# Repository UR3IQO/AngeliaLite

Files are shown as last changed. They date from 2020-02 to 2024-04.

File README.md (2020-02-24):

# **AngeliaLite**
## **Overview**

A two ADCs HF/50MHz direct sampling SDR transceiver with OpenHPSDR v2 compatible protocol.

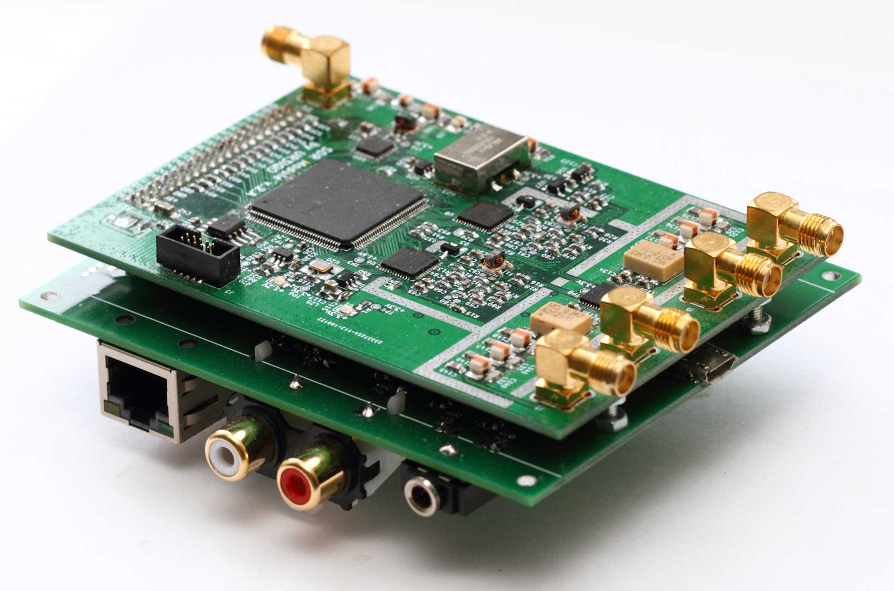
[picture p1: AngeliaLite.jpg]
AngeliaLite SDR transceiver


Some time ago I designed an SDR module for my other projects. The module has two RX inputs (with DVGA and 14bits AD9255 ADC) and one TX output (with 14bits AD9744 DAC). There are also Cyclone 4 FPGA EP4CE22E22, configuration memory and all necessary components for clocking and power it up. The ADCs are clocked at 77.76MHz and the DAC is clocked at 155.52MHz by the low noise ABLJO-155.52MHz VCXO.

The goal of this project was to build a base for the OpenHPSDR compatible SDR transceiver based on that SDR module. The FPGA firmware is based on the OpenHPSDR Angelia code, the NCO code is from the HermesLite2 project. There were many changes in the code to fit 4 DDCs into the relatively small and low pin count EP4CE22E22 FPGA, some changes were requied because of the different ADC/DAC sample rates.

The second board contains Eternet PHY, standard ALEX, OC, keyer and PTT interfaces, four analog inputs, diagnostic LEDs, switching regulator (so it can be powered from the single 12V supply). There is also STM32F072 MCU on the secons board.

You need to add some RX filtering and TX amplifier with LPFs to get a full featured transceiver.

**There are some limitations:**
* The maximun supported output samplerate is 192kSPS
* There is no audio CODEC on the boards
* The Ethernet connection has 100Mbit/s speed
* The ADC opaerates on the second Nyquist zone on 50MHz band. The board has LPF filter with 65MHz cutoff frequency, so additional selectivity is needed to avoid images reception. It can be as simple as switchable 30MHz LPF and 50MHz bandpass filter.
* There is no TX power amplifier at the DAC output - just an LPF filter-diplexer. So, you will need some amplfication/filtering in the TX path.
* Altera USBBlaster or similar JTAG adapter is needed for FPGA firmware update

The SDR operates with the ***SDR Console v3*** and ***Thetis***.

## **Specifications**
**General**| |
:-|-|
Architecture | *Direct Sampling DDC/DUC Transceiver*  |
Interface | *Ethernet (100Mb/s)*  
TCXO Stability | *±0.5 PPM*  
RX ports | *Two SMA connectors (each ADC has dedicated input)*  
TX ports | *SMA connector* 

**Electrical**|
:-|
13.8v DC @ 0.5A|

**Mechanical** | |
:-|-|
Weight | *100g (approx.)*  
Dimensions (two boards stacked) | *100mm x 85mm x 35mm*

**Receiver**| |
:-|-|
Receiver Architecture | *Direct Sampling / Digital Down Conversion*  
ADC | *Dual 14 bit Phase Synchronous ADCs @ 77.76MSPS. Hardware supports 4 independent receivers assignable to either ADC*  
Frequency Coverage | *1MHz to 35MHz (1st Nyquist zone) and 45MHz to 65MHz (2nd Nyquist zone), reception below 1MHz is possible with some RX parameters degradation*  
Input filtering | *LPF with 65MHz cutoff frequency*  
Attenuator | *0..31dB 1dB step attenuator*  

**Transmitter**| |
:-|-|
Transmitter Architecture | *Digital Up Conversion*  
DAC | *14 bit @ 155.52MSPS*  
RF Output Power | *-3dBm*
Transmitter phase noise | -140dBc/Hz (at >1kHz offset and max. drive settings)

**IOs:**|
:-|
RCA PTT in, PTT Out |
3.5mm Jack CW Key |
2.54mm pin headers for ALEX, 7 freely programmable open collector outputs, analog Inputs (4channel + power supply monitoring), two digital inputs |
SMA connector for 10MHz reference input/output |
SMA connector for 155.52MHz reference output |
RJ45 Ethernet LAN Connector |

## **Measurements**
The receiver BW was 500Hz during the measurements.

### **MDS / NF / FS level / BDR**

ATT | MDS | NF | FS level | BDR |
---: | ---: | ---: | ---: | ---: |
  0dB| -133dBm | 14dB | -13dBm | 120dB |  
-10dB| -127dBm | 20dB | -2dBm | 125dB |
-20dB| -117dBm | 30dB | +9dBm | 126dB |
-30dB| -107dBm | 40dB | - | - |

### **RMDR / SSB noise**

Offset | RMDR | SSB noise
---: | ---: | ---:
1kHz | 111dB | -138dBc/Hz
2kHz | 113dB | -140dBc/Hz
5kHz | 117dB | -144dBc/Hz
10kHz | 121dB | -148dBc/Hz
20kHz | 124dB | -151dBc/Hz

### **IMD3 Performance**

The usual method of determining IMD3 receiver performance does not give useful data when testing direct sampling receiver (because of IMD products does not follow cubical law). So, the IMD3 performance data presented in graphical form showing IM3 levels depending of the test tones levels for the different attenuator settings.

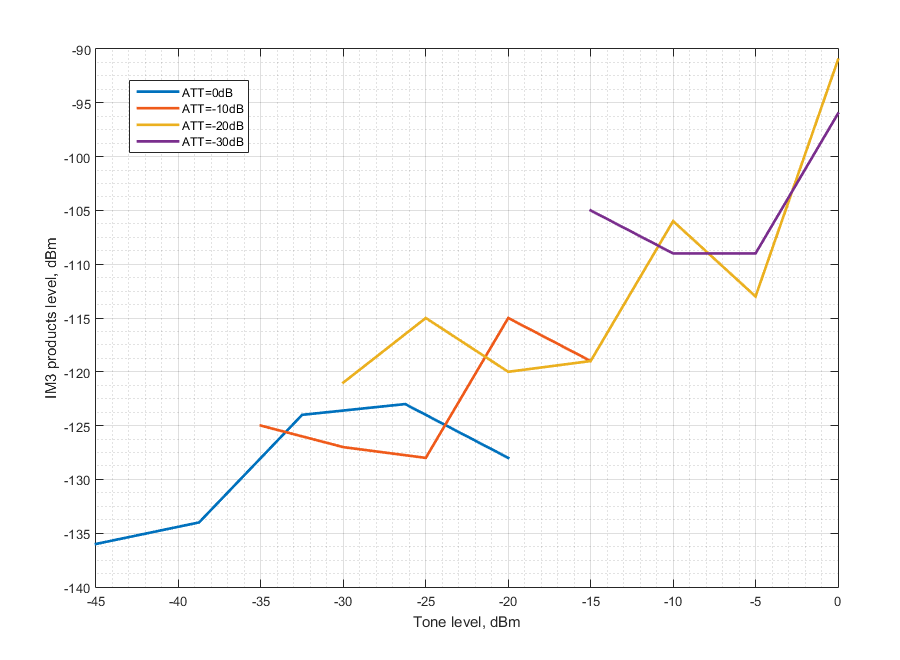
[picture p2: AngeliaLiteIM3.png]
IMD3 Performance


## **Image rejection and DDC Decimation Filters**

AngeliaLite uses different ADC/DAC sampling frequencies, so all decimation stages and filters were redesigned for the new decimation ratios.  

### **SDR module input (analog LPF)**

LPF filter at the SDR module input rejects ADC aliases. Only signals in the 1st and 2nd Nyquist zones passed. As you can see some additional filtering is required to separate signals in the first and second zones and improove rejection in the third and higher zones. Here is the LPF response:

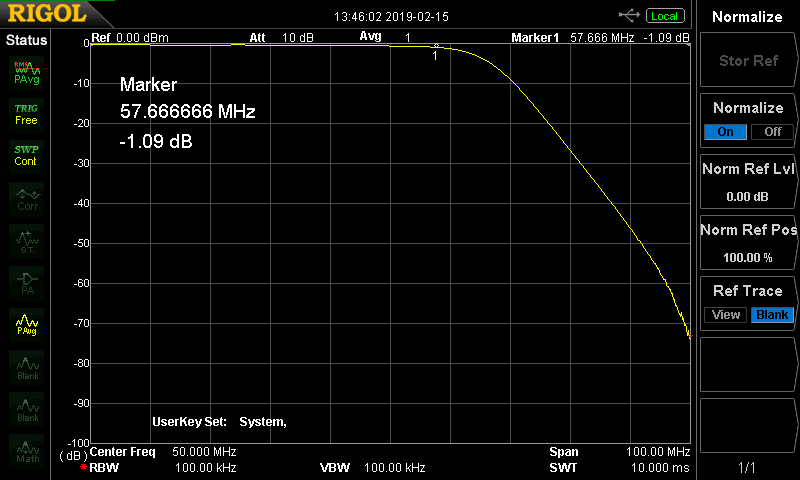
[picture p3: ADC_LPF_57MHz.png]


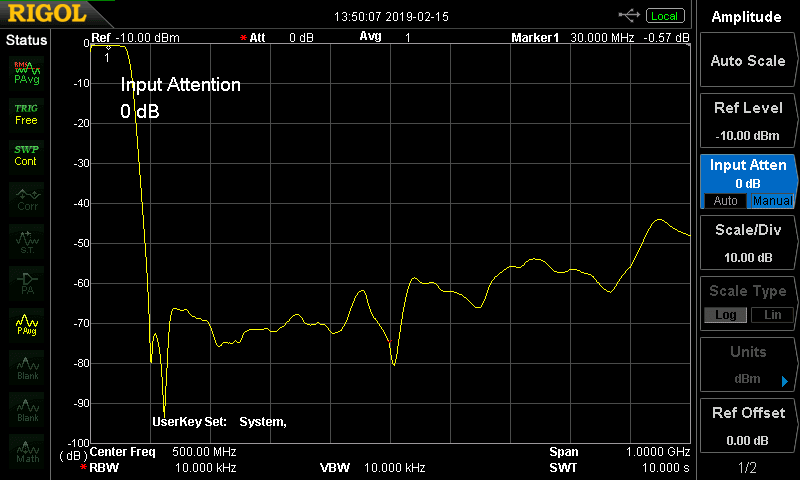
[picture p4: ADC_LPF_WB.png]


### **First stage 9x decimation (digital CIC filter)**

When the signal is decimated aliasing occurs, so some filtering is needed. CIC filter provides such filtering for the first 9x decimation. The worst case alias rejection is **116dB**. Here is the filter response:

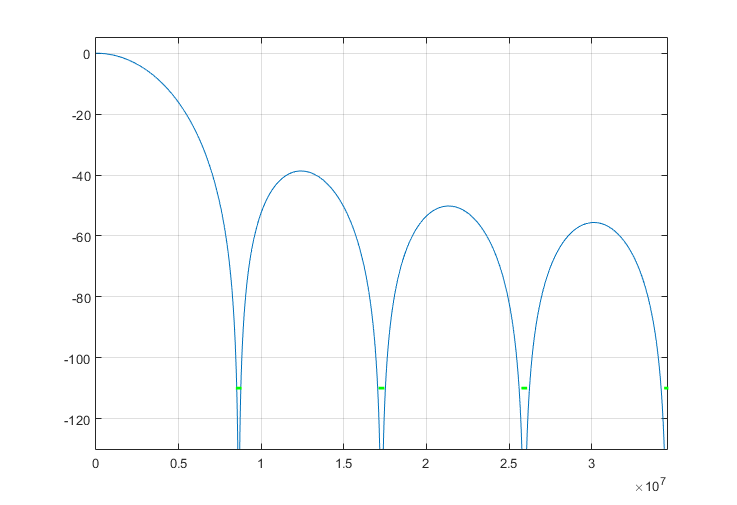
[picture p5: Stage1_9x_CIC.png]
First stage CIC


### **Second stage 5x/10x/20x decimation (digital CIC flter)**

The second decimation stage and one more CIC filter. The worst case alial rejection is **121dB** (for 5x decimation 96kHz bandwidth). Here is filter response:

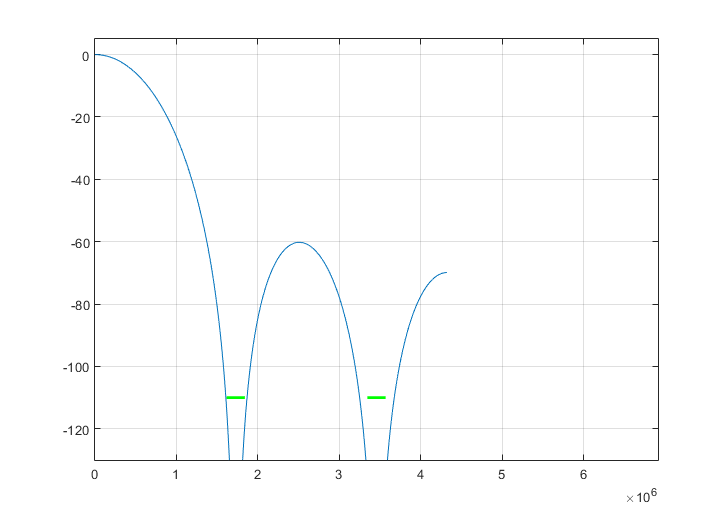
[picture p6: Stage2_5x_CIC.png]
Second stage CIC


### **Third stage 9x decimation (digital FIR filter)**

The aliases of the last decimation by 9 are suppressed by the FIR filter. AngeliaLite uses relatively small and inexpensive FPGA, so last stage FIR filter is optimized for the minimum logic/memory FPGA resources use. The performance is limited by the 18bits FIR filter coefficients, but rejection is still at a respectable **100dB**. Here are the calculated ideal filter response (blue line) and the real one with quantized coefficients (red line):

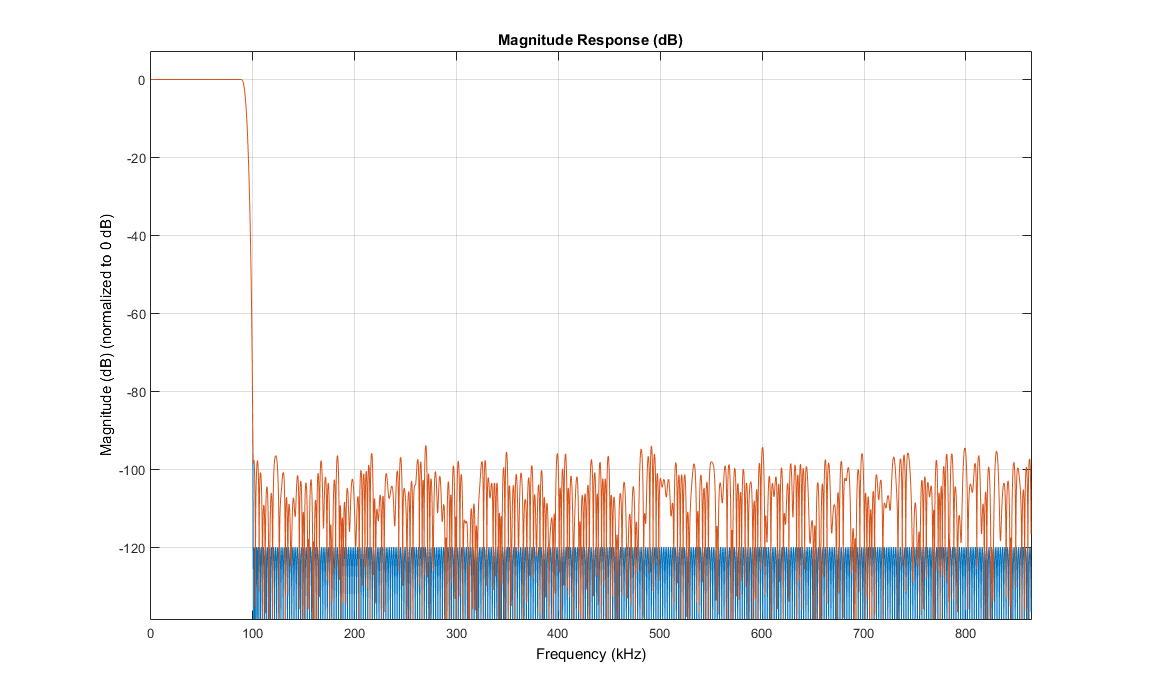
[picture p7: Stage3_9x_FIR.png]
Third stage FIR


## **Board connections**
**SDR module**
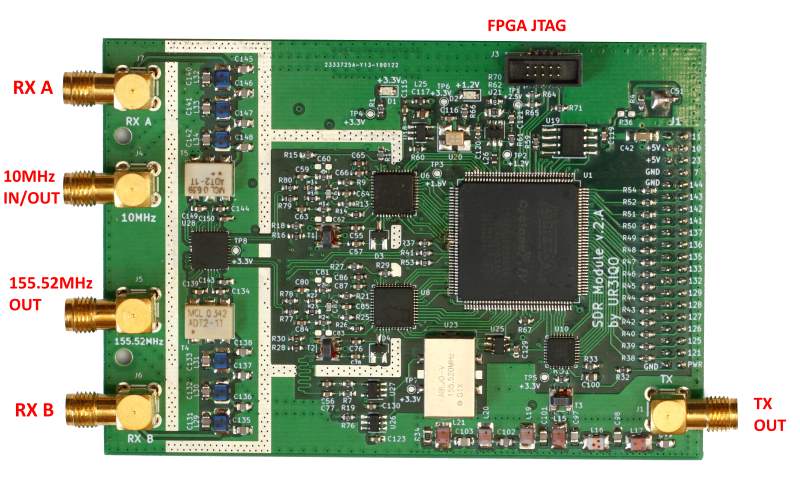
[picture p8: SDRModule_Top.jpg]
SDR module by UR3IQO


**AngeliaLite mainboard**
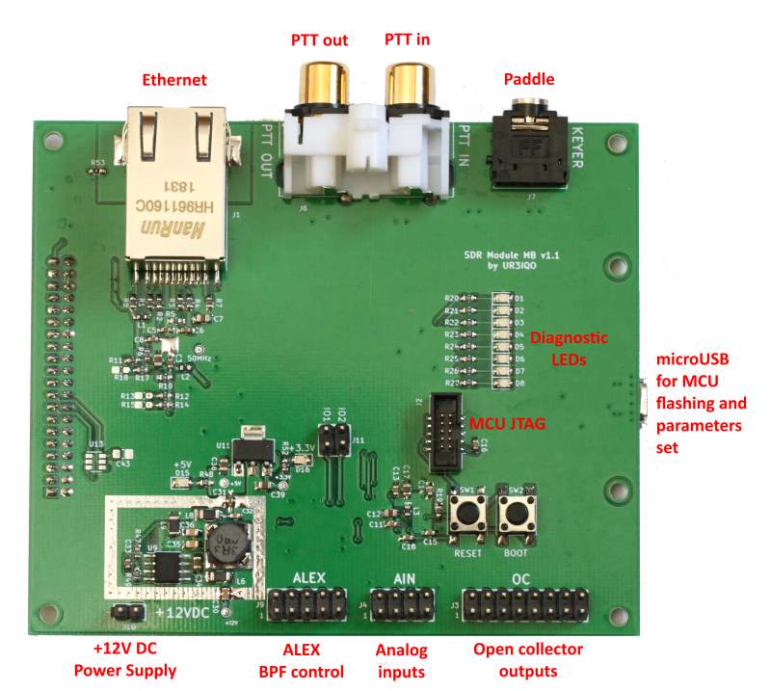
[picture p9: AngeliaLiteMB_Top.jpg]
AngeliaLite Motherboard


73!
Oleg UR3IQO

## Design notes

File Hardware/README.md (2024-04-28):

# SDRModule and AngeliaLite Mainboard
In this folder you can find SDR module and AngeliaLite Mainboard schematics.

# Assembly instructions
## AngeliaLite Mainboard v1.1
***Important!***

Do ***not install*** the following components:
- U10 (74LVC1G04)
- U13 (25AA02E48T)
- C37
- C43
- R13
- R15
- R18
- R50
- R59
- R32
- R35

***Install*** the following components: 
- R17 10 kOhm
- R33 0 Ohm
- R34 0 Ohm

## SDRModule v2.B
Do ***not install*** the following components:
- R35
- R72
- R75
- L23

Assemble the power supply circuits firstly and do a brief check. Proceed with the other components when you see the correct voltages supplyed by the regulators. This may save you some money and time ;)

# Troubleshooting

## Diagnostic LEDs on the Motherboard 
- **LED1** flash for ~0.2 second whenever the PHY receives (rgmii_rx_activ)
- **LED2** flash for ~0.2 second whenever the PHY transmits (rgmii_tx_active)
- **LED3** is not used
- **LED4** flash for ~0.2 seconds whenever traffic to the boards MAC address is received 
- **LED5** displays state of Ethernet PHY negotiations:
   - fast flash if no Ethernet connection
   - slow flash if 100T
   - swaps between fast and slow flash if not full duplex
- **LED6** displays state of DHCP negotiations:
   - on if success
   - slow flash if fail
   - fast flash if time out 
   - swap between fast and slow if using a static IP address
- **LED7** flash for ~0.2 seconds whenever udp_rx_active
- **LED8** (**STATUS**) flash if FPGA and MCU firmware are running and FPGA<->MCU SPI bus operates properly

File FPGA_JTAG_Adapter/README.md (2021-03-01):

# **AngeliaLite**
## **FPGA JTAG Adapter**

This directory contains schematics and gerber files for the JTAG adapter. It is used to connect the standard 2x5 pins 2.54mm pin grid connector (used in the Altera Byte Blaster or other similar JTAG cables) to the miniature BH1.27-10SMD connector used in the AngeliaLite.

The pinouts of the both connectors are the same. The connectors are mounted on the opposite sides of the PCB:

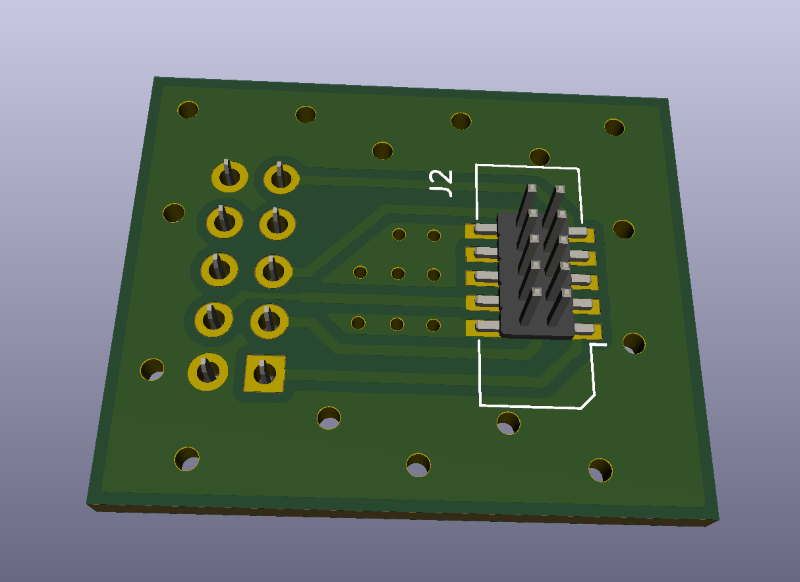
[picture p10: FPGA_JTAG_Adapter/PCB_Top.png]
FPGA JTAG Adapter PCB top

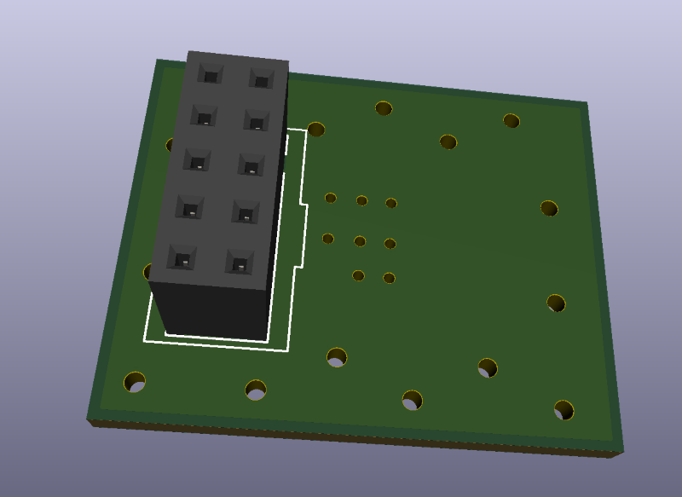
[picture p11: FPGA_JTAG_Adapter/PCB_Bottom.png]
FPGA JTAG Adapter PCB bottom


## **How to use the adapter**

The usage is straightforward - just plug the adapter to the Altera USB Byte Blaster (or compatible JTAG cable). And use the flat cable with two IDC1.27-10 sockets to connect adapter and AngeliaLite board.

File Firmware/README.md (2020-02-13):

# Firmware for the AngeliaLite
The FPGA folder contains FPGA source code and binaries for the SDR module Cyclone 4 FPGA.  
The MCU folder contains binary (DFU image) for the STM32F072 MCU

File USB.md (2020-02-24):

# **How to use microUSB port on the AngeliaLite Mainboard**

There is a microUSB connector on the AngeliaLite Mainboard. It is connected to the board MCU (STM32F072) and is used to:
- Firmware flashing to the MCU
- Checking MAC/IP addresses 
- Seting IP address (and also to select DHCP/static IP)

## **Firmware flashing**
You can flash the MCU firmware using the ST DFU utilities for the STM32. Connect AngeliaLite Mainboard to the PC computer (using microUSB-USB cable), turn it on holding BOOT button, release BOOT button. The MCU will enter bootloader mode and you will be able to flash it.

## **Setting IP address**
By default AngeliaLite uses DHCP to obtain valid IP address or rolls back to APIPA address if it can not get IP address. You can program static IP address useing microUSB port on the AngeliaLite Mainboard.

Connect AngeliaLite Mainboard to the PC computer (using microUSB-USB cable), turn it on. A new communication port should be found by your PC. Connect to those port using terminal software (for example Putty), use default parameters.

After connection the following commands will be available:
| Command | Description |
|---|---|
|**H;** | Brief help message|
|**I;**|show IP address|
|**I aaa.bbb.ccc.ddd;**|set static IP address *aaa.bbb.ccc.ddd*|
|**I DHCP;**|obtain IP address from DHCP server or use APIPA|adress if DHCP fails
|**M;**|show MAC address|
|**V;**|show firmware version and serial number|

The changes will be effective after the board restarts

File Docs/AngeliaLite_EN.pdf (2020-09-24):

## AngeliaLite - OpenHPSDR compatible transceiver

Oleg Skydan UR3IQO

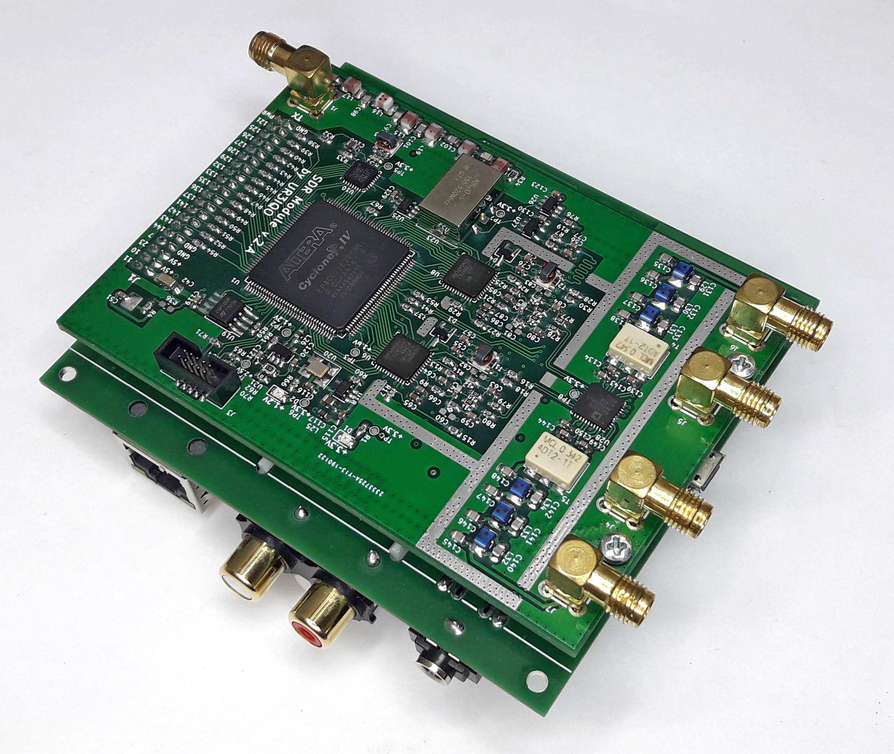
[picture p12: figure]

### Description

AngeliaLite is intended to be used as the base of the OpenHPSDR compatible transceiver. You need to add just some additional filtering for receiver and PA/LPFs for transmitter to make a full featured high performance HF SDR transceiver. A VHF/microwave transceiver can also be made by adding transverter to the AngeliaLite.

AngeliaLite consists of two boards - the SDR module and the interface board.

The SDR module has two RX inputs (with DVGA and 14bits AD9255 ADC) and one TX output (with 14bits AD9744 DAC). There are also Cyclone 4 FPGA EP4CE22E22, configuration memory and all necessary components for clocking and power it up. The ADCs are clocked at 77.76MHz and the DAC is clocked at 155.52MHz by the low noise ABLJO-155.52MHz VCXO.

The interface board contains Eternet PHY, standard ALEX, OC, keyer and PTT interfaces, four analog inputs, diagnostic LEDs, switching regulator (so it can be powered from the single 12V supply), microcontroller (used to interface SDR module to standard OpenHPSDR interfaces, IP and MAC addresses management) and power supply to power boards from the single 12V power supply.

The schematics for both boards, FPGA source code and FPGA/MCU compiled firmware are available on the GitHub (https://github.com/UR3IQO/AngeliaLite ).

The FPGA firmware is based on the OpenHPSDR Angelia code, the NCO code is from the HermesLite2 project. There were many changes in the code to fit 4 DDCs into the relatively small and low pin count EP4CE22E22 FPGA, some changes were required because of the different ADC/DAC sample rates and different Ethernet PHY chip.

There are some limitations compared to the OpenHPSDR Angelia board:

- The maximum supported output samplerate is 192kSPS.
- There is no audio CODEC on the boards.
- The Ethernet connection has 100Mbit/s speed.
- The ADC operates on the second Nyquist zone on 50MHz band. The board has LPF filter with 60MHz cutoff frequency, so additional selectivity is needed to avoid image reception. It can be as simple as switchable 30MHz LPF and 50MHz bandpass filter.
- There is no TX power amplifier at the DAC output - just an LPF filter-diplexer. So, you will need some amplification/filtering in the TX path.
- Altera USBBlaster or similar JTAG adapter is needed for FPGA firmware update

The FPGA code implements OpenHPSDR protocol version 2. The AngeliaLite operates with the SDR Console v3 and Thetis.

### Specifications

General
Architecture | Direct Sampling DDC/DUC Transceiver
Interface | Ethernet (100Mb/s)
TCXO Stability | ±0.5 ppm
RX ports | Two SMA connectors (each ADC has dedicated input)
TX ports | SMA connector

Electrical
Supply voltage | 8..15V DC
Supply current | 0.5A

Mechanical
Weight | 100g (approx.)
Dimensions (two boards stacked) | 100mm x 85mm x 35mm

Receiver
Receiver Architecture | Direct Sampling / Digital Down Conversion
ADC | Two 14 bit Phase Synchronous ADCs @ 77.76MSPS. Hardware supports 4 independent receivers assignable to either ADC
Frequency Coverage | 1MHz to 35MHz (1st Nyquist zone) and 45MHz to 65MHz (2nd Nyquist zone), reception below 1MHz is possible with some RX parameters degradation
Input filtering | LPF with 65MHz cutoff frequency
Attenuator | 0..31dB 1dB step attenuator

Transmitter
Transmitter Architecture | Digital Up Conversion
DAC | 14 bit @ 155.52MSPS
RF Output Power | -3..-5dBm
Transmitter phase noise | -140dBc/Hz (at >1kHz offset and max. drive settings)

IO interfaces
RCA PTT in, PTT Out
3.5mm Jack CW Key
2.54mm pin headers for ALEX, 7 freely programmable open collector outputs, analog Inputs (4channel + power supply monitoring), two digital inputs
SMA connector for 10MHz reference input/output
SMA connector for 155.52MHz reference output
RJ45 Ethernet LAN Connector

### Receiver measurements

The BDR/RMDR/IMD tests were made using two ultra low noise XTAL oscillators. The receiver bandwidth was 500Hz during these tests.

MDS / NF / FS level / BDR
ATT | MDS | NF | FS level | BDR
0dB | -133dBm | 14dB | -13dBm | 120dB
-10dB | -127dBm | 20dB | -2dBm | 125dB
-20dB | -117dBm | 30dB | +9dBm | 126dB
-30dB | -107dBm | 40dB | - | -

RMDR / SSB noise
Offset | RMDR | SSB noise
1kHz | 111dB | -138dBc/Hz
2kHz | 113dB | -140dBc/Hz
5kHz | 117dB | -144dBc/Hz
10kHz | 121dB | -148dBc/Hz
20kHz | 124dB | -151dBc/Hz

IMD3 Performance

The usual method of determining IMD3 receiver performance does not give useful data when testing direct sampling receiver (because of IMD products does not follow cubical law). So, the IMD3 performance data presented in graphical form showing IM3 levels depending of the test tones levels for the different attenuator settings.

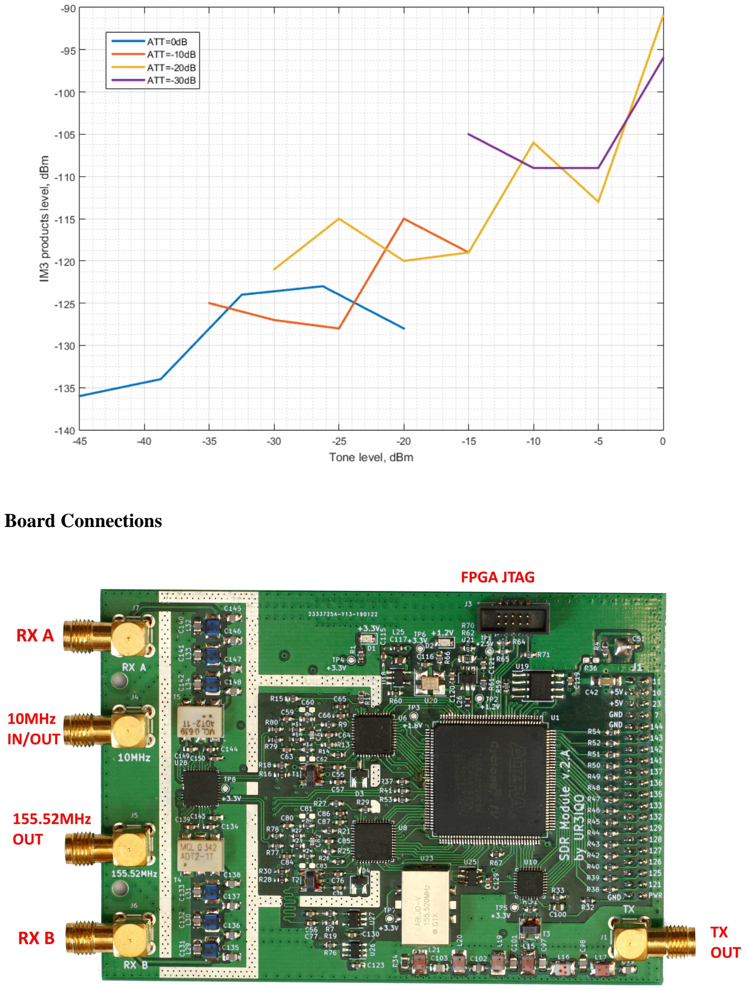
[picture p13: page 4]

Board Connections

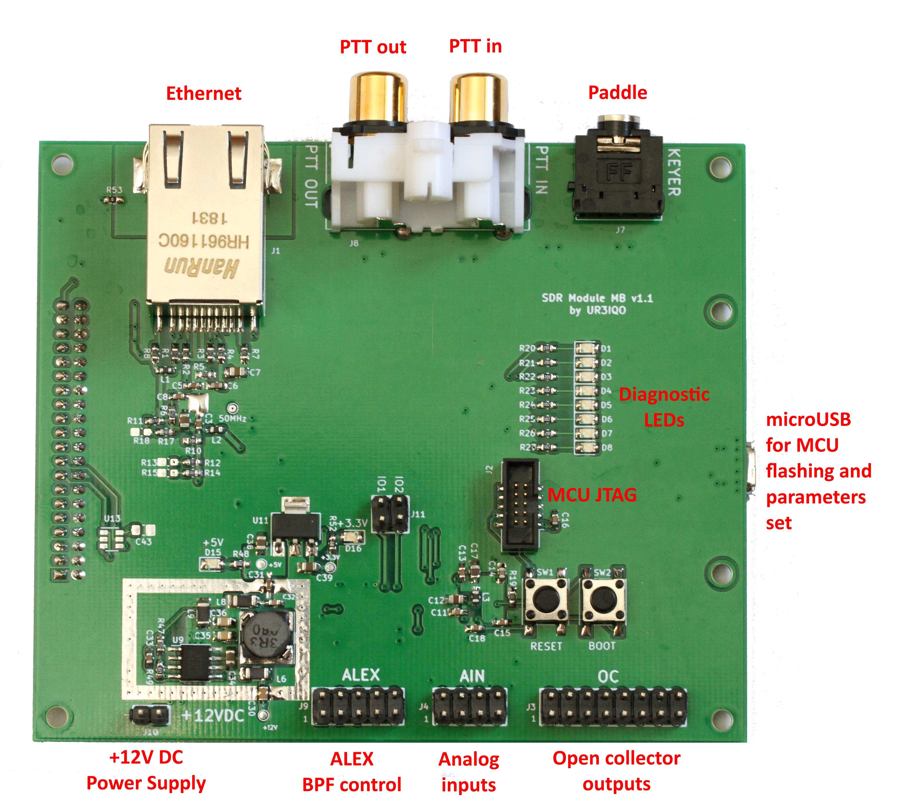
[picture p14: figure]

### Using the USB port on the interface board

Using the USB port on the interface board you can:
- update MCU firmware
- selecting IP address assignment and set static IP address
- check the board MAC address and serial number
- check MCU firmware version
- set ADC dither override options

Connecting to the AngeliaLite service console

Connect microUSB port on the board to the computer and turn on the AngeliLite power supply. The computer will install the virtual COM port driver. Open Device Manager to check the port number assigned to the board. Run terminal program (the PuTTY will be used in examples).

Set the COM port number assigned to the board:

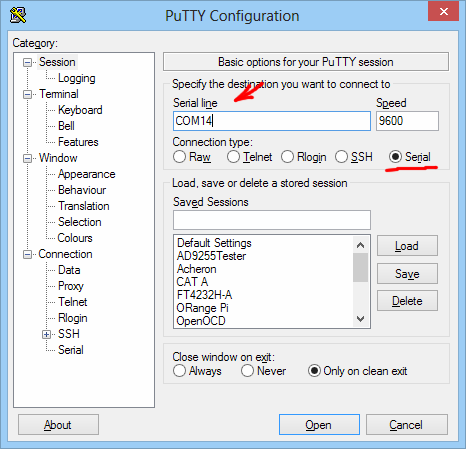
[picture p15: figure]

Set Local Echo terminal option:

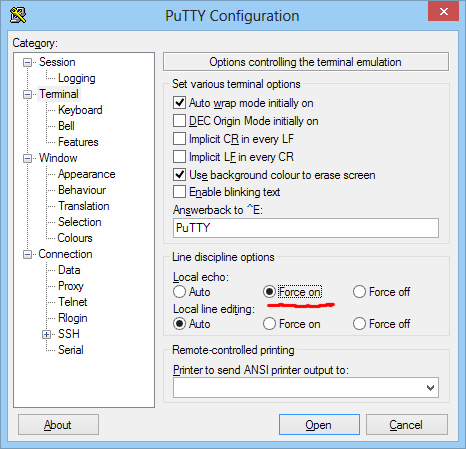
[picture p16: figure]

Now press the Connect button, the terminal window with AngeliaLite service console will open.

The command you can issue in the AngeliaLite service console starts with the command (one letter) following by optional command parameter, each command ends with the semicolon.

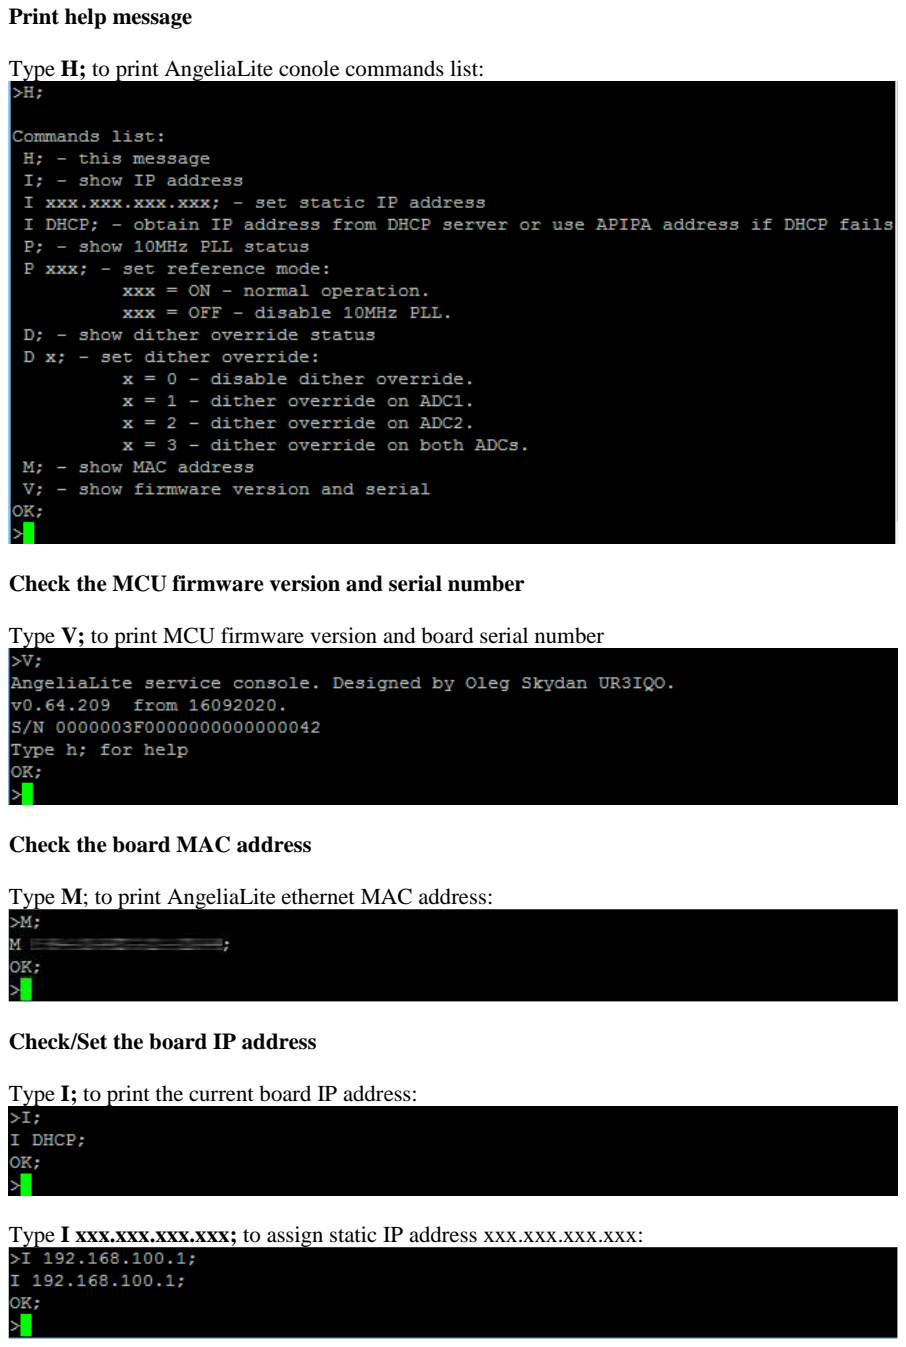
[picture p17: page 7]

Print help message

Type H; to print AngeliaLite conole commands list:

Check the MCU firmware version and serial number

Type V; to print MCU firmware version and board serial number

Check the board MAC address

Type M; to print AngeliaLite ethernet MAC address:

Check/Set the board IP address

Type I; to print the current board IP address:

Type I xxx.xxx.xxx.xxx; to assign static IP address xxx.xxx.xxx.xxx:

Type I DHCP; to use DHCP to assign IP addres or APIPA address if DHCP will fail

NOTE: you should cycle the power of the AngeliaLite to use the new IP address.

Check/Set ADC dithering override

It is recommended to keep ADC dithering enabled for the AngeliaLite, but the SDR software may not allow user to control ADC dithering. So there is ADC dithering override option that can be controlled using the AngeliaLite service console. If the dithering override bit is set the ADC dithering will be turned on independently of the SDR software settings.

Type D; to check the ADC dithering override status:

Type D x; to change ADC dithering override flags:

See the table below for the x parameter description:
Parameter value | Description
0 | ADC dithering override is OFF, the SDR software will control dithering
1 | ADC dithering override is ON for the ADC1 only
2 | ADC dithering override is ON for the ADC2 only
3 | ADC dithering override is ON for both ADCs

Close the terminal program and disconnect USB cable when you done with the AngeliaLite service console.

Updating MCU firmware

You will need DfuSe Demo software available at the ST web site: https://www.st.com/en/development-tools/stsw-stm32080.html

Connect board to the computer USB port, turn the board power on when holding the BOOT button on the interface board. Alternatively you can hold the BOOT button and press the RESET button. Then release the BOOT button. The MCU will start the internal DFU bootloader and you will be able to flash it using the DFU image from the AngeliaLite GitHub: https://github.com/UR3IQO/AngeliaLite/tree/master/Firmware/MCU

Please see DfuSe Demo documentation how to load the image into the MCU flash memory.

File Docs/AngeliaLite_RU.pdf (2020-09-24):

# AngeliaLite - OpenHPSDR совместимый трансивер

Олег Скидан UR3IQO


### Введение

AngeliaLite предназначен | для | использования | в | качестве | основы | OpenHPSDR
совместимого трансивера. Для того чтобы получить полноценный SDR КВ трансивер достаточно добавить фильтры на вход приемника и усилитель мощности с ФНЧ. Также AngeliaLite удобен для работы на УКВ/СВЧ диапазонах - достаточно подключить трансвертер, чтобы получить полноценный SDR УКВ трансивер.

AngeliaLite состоит из двух плат - SDR модуля и интерфейсной платы.

У SDR модуля два входа приемников (каждый с программируемым УВЧ и 14битным АЦП AD9255) и один выход передатчика (используется 14битный ЦАП AD9744). Также на плате SDR модуля установлены ПЛИС Cyclone 4 EP4CE22E22, конфигурационная память, а также все необходимые компоненты для питания и тактирования различных элементов модуля. Тактирование модуля осуществляется от малошумящего кварцевого генератора ABLJO-155.52MHz. Тактовая частота АЦП 77.76MHz, ЦАП работает на
частоте 155.52MHz.

Интерфейсная плата содержит Ethernet PHY, стандартные интерфейсы ALEX, OC, интерфейсы для подключения манипулятора телеграфного ключа и PTT, четыре аналоговых входа, диагностические светодиоды, импульсный стабилизатор +5В (который позволяет трансиверу работать в широком диапазоне питающих напряжений с минимальным нагревом и хорошей эффективностью и микроконтроллер (который используется для управления IP/MAC адресацией и обеспечивает работу стандартных интерфейсов OpenHPSDR).

Принципиальные схемы обеих плат, а также исходный код для ПЛИС и скомпилированные прошивки для ПЛИС и микроконтроллера доступны на GitHub
(https://github.com/UR3IQO/AngeliaLite ).

Прошивка ПЛИС основана на исходном коде проекта OpenHPSDR Angelia, NCO используется от проекта HermesLite2. В исходный код было внесено много изменений для того, чтобы в ПЛИС с небольшой логической емкостью вместить четыре приемника. Также изменения потребовались в силу других частот дискретизации АЦП/ЦАП (все децимационные/интерполяционные фильтры были заново пересчитаны, а децимационный КИХ фильтр приемника был полностью переписан заново), а также использования
другого чипа Ethernet PHY.

AngeliaLite имеет некоторые ограничения по сравнению с оригинальным проектом

### OpenHPSDR Angelia:

- Максимально поддерживаемая частота дискретизации на выходе DDC 192kSPS.
- На плате нет аудиокодека.
- Подключение по Ethernet осуществляется со скоростью 100Mbit/s.
- В диапазоне 50МГц АЦП работает во второй зоне Найквиста. На плате установлены ФНЧ с частотой среза около 60МГц, поэтому требуется дополнительная фильтрация, чтобы подавить наложения. Достаточно простого ФНЧ с частотой среза 30МГц и полосового фильтра на диапазон 50МГц.
- На плате нет драйвера передатчика. Поэтому может потребоваться дополнительное усиление сигнала для подключения усилителя мощности.
- Для обновления прошивки потребуется Altera USBBlaster или аналогичный JTAG адаптер

В прошивке ПЛИС реализован "новый" протокол OpenHPSDR (протокол второй версии).
AngeliaLite может работать с программами SDR Console v3 и Thetis.

### Параметры

Общие
Архитектура | DDC/DUC трансивер с прямой оцифровкой
Интерфейс | Ethernet (100Mb/s)
Стабильность TCXO | ±0.5 ppm
Подключение приемника | Два SMA разъема (отдельный вход для каждого АЦП)
Подключение передатчика | SMA разъем
Вес | Около 100гр
Размеры (сборка из двух плат) | 100mm x 85mm x 35mm

Питание
Напряжение источника питания | 8..15V DC
Потребляемый ток | <0.5A

Приемник
Архитектура приемника | Прямая оцифровка
АЦП | Два 14 битных АЦП работающих с частотой дискретизации 77.76MSPS и синхронизированных по фазе. Поддерживается до 4х независимых приемников подключаемых к любому АЦП
Диапазон частот | 1..35MHz (первая зона Найквиста) 45..65MHz (вторая зона Найквиста) возможен прием ниже 1MHz с некоторым ухудшением параметров
Входная фильтрация | ФНЧ с частотой среза 60МHz
Аттенюатор | 0..31dB с шагом 1dB

Передатчик
Архитектура передатчика | Прямое формирование на частоте передачи
ЦАП | 14 бит @ 155.52MSPS
Выходная мощность | -3..-5dBm
Фазовый шум на выходе передатчика | -140dBc/Hz (при отстройке более 1kHz и установленной максимальной мощности)

Интерфейсы

### RCA PTT вход, PTT выход

3.5mm Jack для подключения CW манипулятора
Штыревые разъемы с шагом 2.54mm (для подключения ПФ ALEX, 7 свободно программируемых выходов, аналоговые входы - 4 канала и мониторинг напряжения питания), два цифровых входа
SMA разъем для входа/выхода опорного сигнала с частотой 10MHz
SMA разъем с опорным сигналом 155.52MHz
RJ45 Ethernet разъем подключения компьютерной сети

### Измерения параметров приемников

Измерения BDR/RMDR/IMD3 DR проводились с использованием ультра малошумящих кварцевых генераторов (уровень бокового шума менее -180дБн/Гц при отстройке более 10кГц). Полоса пропускания приемника при проведении тестов была 500Гц.

### MDS / NF / FS level / BDR

ATT | MDS | NF | Уровень FS | BDR
0dB | -133dBm | 14dB | -13dBm | 120dB
-10dB | -127dBm | 20dB | -2dBm | 125dB
-20dB | -117dBm | 30dB | +9dBm | 126dB
-30dB | -107dBm | 40dB | - | -

### RMDR / шум

Отстройка | RMDR | Шум
1kHz | 111dB | -138dBc/Hz
2kHz | 113dB | -140dBc/Hz
5kHz | 117dB | -144dBc/Hz
10kHz | 121dB | -148dBc/Hz
20kHz | 124dB | -151dBc/Hz

Динамический диапазон по интермодуляции третьего порядка

У приемников с прямой оцифровкой уровень продуктов интермодуляции может не следовать кубическому закону. Поэтому традиционные методы, используемые, чтобы охарактеризовать ДД приемника по интермодуляции третьего порядка, плохо подходят. ДД приемника по интермодуляции третьего порядка приведен в виде графика, показывающего уровень продуктов интермодуляции в зависимости от уровня испытательного двухтонового сигнала (по оси Х приведены уровни одного тона двухтонового тестового сигнала) для разных установок коэффициента усиления DVGA (приведены значения соответствующие установкам аттенюатора в программах Thetis и

### SDR Console):

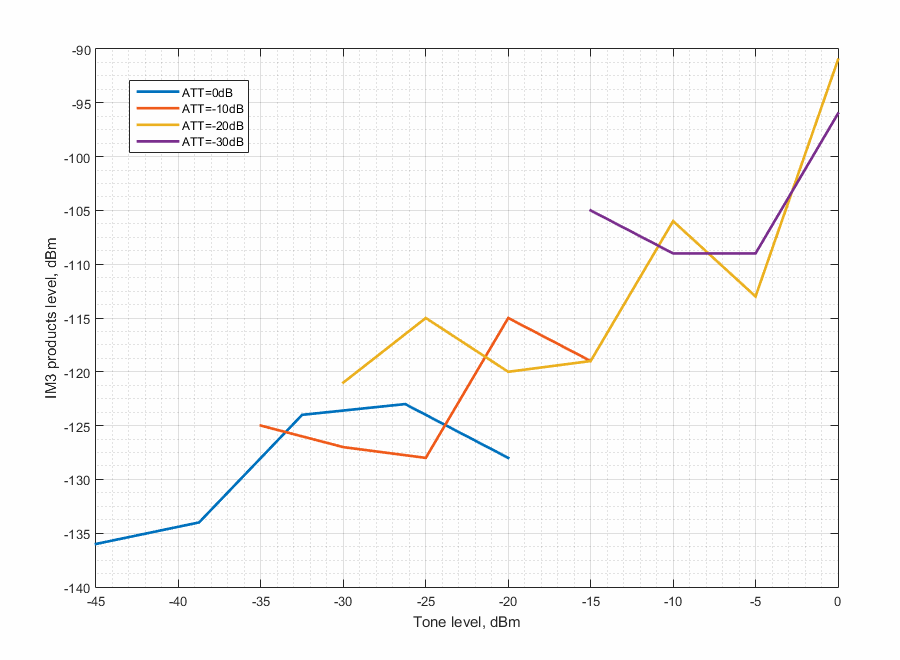
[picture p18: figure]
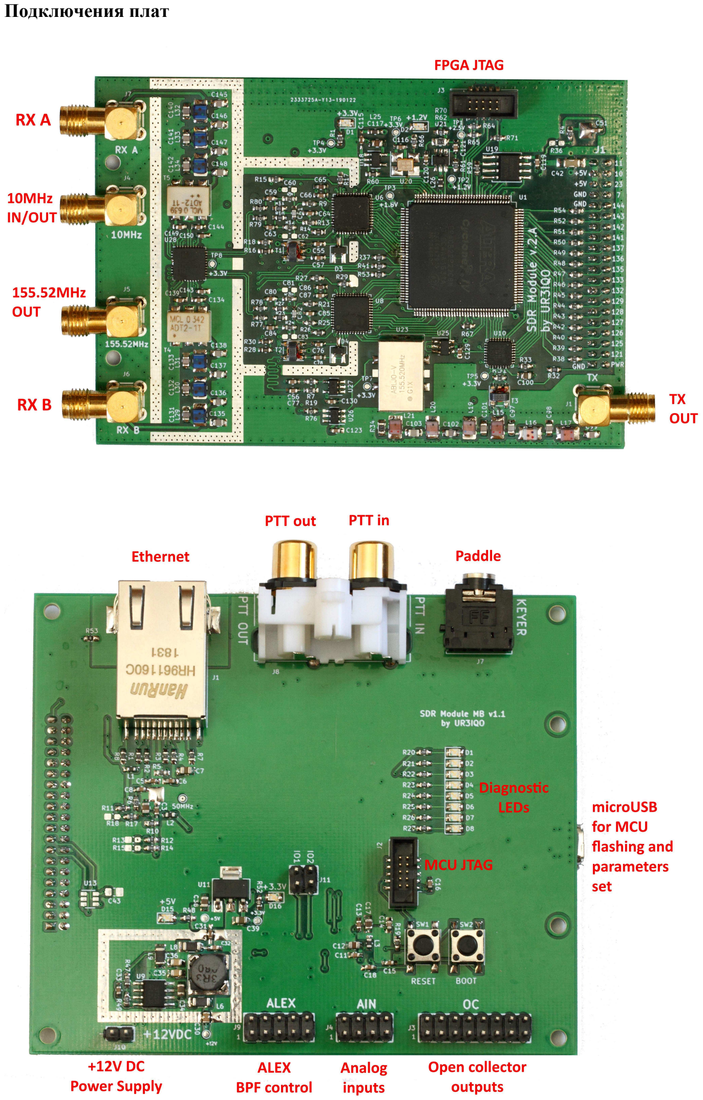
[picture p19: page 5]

Подключения плат

### Использование USB порта на интерфейсной плате

С помощью USB порта на интерфейсной плате возможно:
- загрузить/обновить прошивку контроллера
- выбрать метод назначения IP адреса и установить статический IP адрес
- проверить MAC адрес платы и серийный номер
- проверить версию прошивки контроллера
- установить параметры принудительного включения "дизеринга" АЦП

Подключение к сервисной консоли AngeliaLite

Подключите порт microUSB на интерфейсной плате к компьютеру и включите питание трансивера. ОС компьютера установит драйвера виртуального СОМ порта и назначит ему номер. Откройте Менеджер устройств (Device Manager), чтобы узнать номер назначенного СОМ порта. Запустите терминальную программу (в примерах далее будет использоваться программа PuTTY).


Установите СОМ порт, назначенный трансиверу:

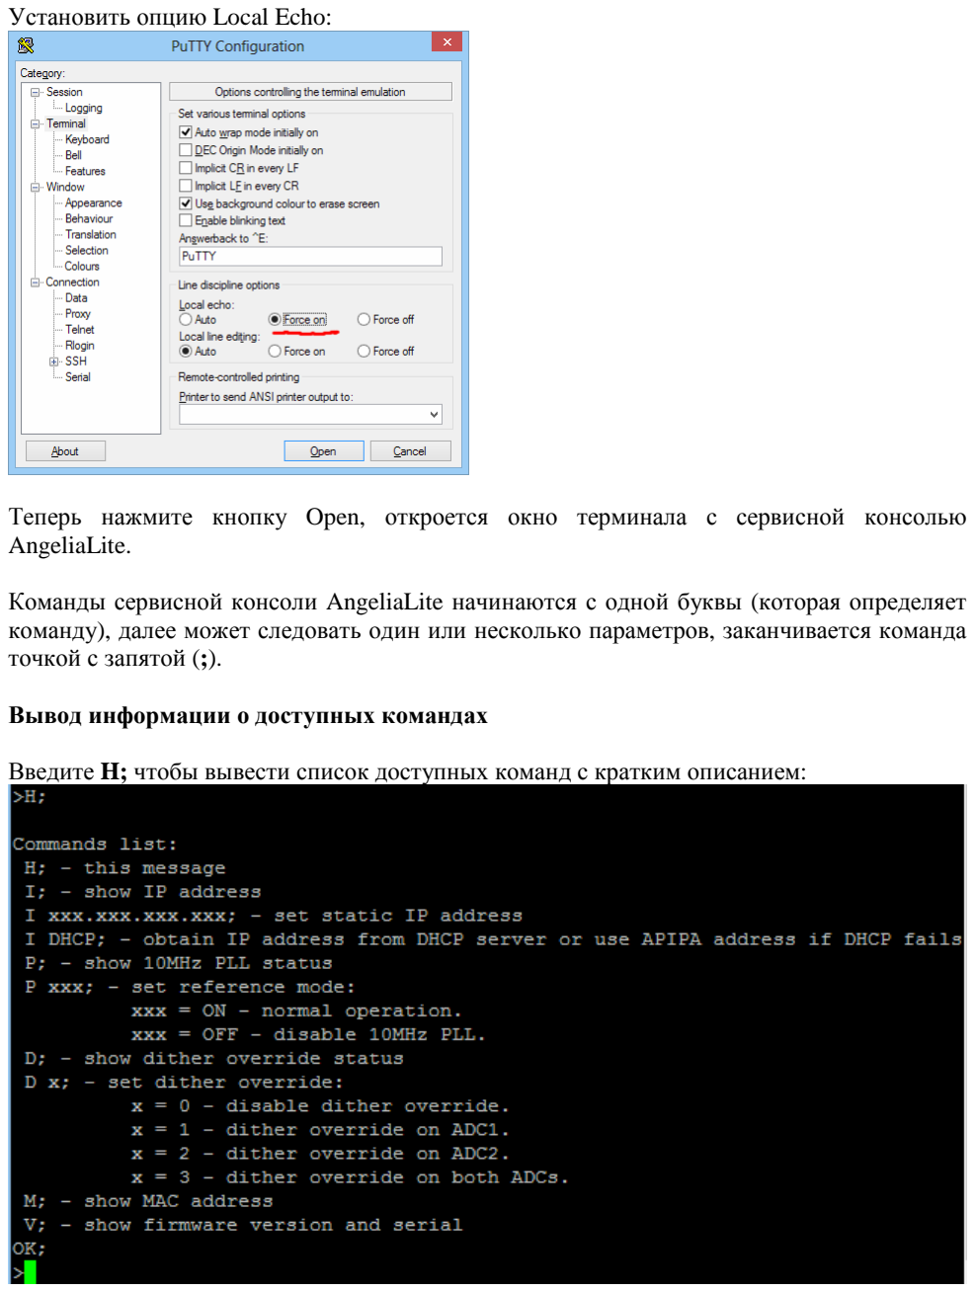
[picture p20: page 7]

Установить опцию Local Echo:

Теперь нажмите кнопку Open, откроется окно терминала с сервисной консолью
AngeliaLite.

Команды сервисной консоли AngeliaLite начинаются с одной буквы (которая определяет команду), далее может следовать один или несколько параметров, заканчивается команда точкой с запятой (;).

Вывод информации о доступных командах

Введите H; чтобы вывести список доступных команд с кратким описанием:

Проверка версии прошивки контроллера и серийного номера платы

Введите V; чтобы вывести версию прошивки контроллера и серийный номер трансивера:

Проверка MAC адреса

Введите M; чтобы вывести МАС адрес трансивера:

Проверка и установка IP адреса

Введите I; чтобы вывести текущий IP адрес трансивера:

Введите I xxx.xxx.xxx.xxx; чтобы установить статический IP адрес xxx.xxx.xxx.xxx:

Введите I DHCP; чтобы использовать DHCP сервис для установки IP адреса или APIPA адрес, если получить адрес с помощью DHCP не получится:

ВНИМАНИЕ: для тог, чтобы изменения вступили в силу необходимо перезапустить трансивер (т.е. выключить и затем включить питание).

Проверка и установка параметров принудительного включения "дизеринга" АЦП

В данном трансивере использованы АЦП для которых рекомендуется функцию "дизеринга" держать включенной. Однако не все программы предоставляют возможности управления этой функцией. Поэтому имеется механизм принудительного включения "дизеринга" посредством сервисной консоли.

Введите D; чтобы проверить параметры принудительного включения "дизеринга":

Введите D x; чтобы изменить параметры принудительного включения "дизеринга":

В таблице ниже приведено описание значений параметра x :
Значение параметра | Описание
0 | принудительное включение "дизеринга" АЦП отключено, функция управляется SDR программой на компьютере
1 | принудительное включение "дизеринга" включено для АЦП1
2 | принудительное включение "дизеринга" включено для АЦП2
3 | принудительное включение "дизеринга" включено для обоих АЦП

Закройте программу терминала по окончании работы с сервисной консолью и отключите USB кабель.

Загрузка/обновление прошивки контроллера

Для загрузки/обновления прошивки контроллера Вам потребуется программа DfuSe Demo доступная для загрузки с сайта ST:

### https://www.st.com/en/development-tools/stsw-stm32080.html

Подключите USB порт на интерфейсной плате к компьютеру, нажмите и удерживайте кнопку BOOT на интерфейсной плате и подайте питание. Также можете при поданном питании нажать кнопку RESET, удерживая кнопку BOOT нажатой. Далее отпустите кнопку BOOT. Контроллер запустится в режиме DFU загрузчика и Вы сможете
обновить/загрузить | прошивку | используя | DFU файл | с | AngeliaLite GitHub:

### https://github.com/UR3IQO/AngeliaLite/tree/master/Firmware/MCU

Процесс обновления/загрузки прошивки описан в документации программы DfuSe Demo.

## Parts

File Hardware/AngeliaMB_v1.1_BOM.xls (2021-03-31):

Позиция | Обозначение | Корпус | Количество | Значение | Поставщик и справка
1 | C41,C19,C23,C22,C21,C20,C18,C16,C15,C14,C13,C11,C28,C40,C37,C33,C32,C9,C8,C6,C5,C3 | C_0603_1608Metric_Pad1,05x0,95mm_HandSolder | 22 | 0.1
2 | C1 | C_0603_1608Metric_Pad1,05x0,95mm_HandSolder | 1 | 470
3 | C25,C29,C27,C26 | C_0603_1608Metric_Pad1,05x0,95mm_HandSolder | 4 | 1000
4 | C2 | C_0603_1608Metric_Pad1,05x0,95mm_HandSolder | 1 | 1,0x10V
5 | C43,C42 | C_0805_2012Metric_Pad1,15x1,40mm_HandSolder | 2 | 0.1
6 | C34 | C_0805_2012Metric_Pad1,15x1,40mm_HandSolder | 1 | 10,0x16V
7 | C24,C17,C12,C39,C38,C10,C7,C4 | C_0805_2012Metric_Pad1,15x1,40mm_HandSolder | 8 | 10,0x6,3V
8 | C36,C35 | C_0805_2012Metric_Pad1,15x1,40mm_HandSolder | 2 | 22,0x6,3V
9 | C31 | NFM18PS_HandSoldering | 1 | NFM18PS105
10 | C30 | NFM21 | 1 | NFM21PC104
11 | D14 | D_SOD-323 | 1 | BZX384-15V
12 | D13,D11,D12 | D_SOD-323 | 3 | BZX384-3V3
13 | D8,D7,D6,D5,D4,D3,D2,D1,D16,D15 | LED_0805_2012Metric_Pad1,15x1,40mm_HandSolder | 10 | LED 0805
14 | D10,D9 | SOT-23 | 2 | BAT54C
15 | F1 | R_1206_3216Metric_Pad1,42x1,75mm_HandSolder | 1 | 2A
16 | J1 | HR961160C | 1 | HR961160C
17 | J8 | 2xRCA | 1 | 2xRCA
18 | J2 | BH1,27-10S_SMD | 1 | BH1,27-10S
19 | J5 | conn_usb_B_micro_smd | 1 | USB_OTG
20 | J7 | Jack_3,5mm_JC-128_Horizontal | 1 | JC-128
21 | J6 | pin_socket_2mm_20x2 | 1 | PBD2-20, шаг 2мм
22 | J10 | pin_strip_2 | 1 | PLS-02, шаг 2.54мм
23 | J11 | pin_strip_2x2 | 1 | PLD-4, шаг 2.54мм
24 | J4 | pin_strip_4x2 | 1 | PLD-8, шаг 2.54мм
25 | J9 | pin_strip_5x2 | 1 | PLD-10, шаг 2.54мм
26 | J3 | pin_strip_8x2 | 1 | PLD-16, шаг 2.54мм
27 | L2,L1,L4,L3,L5 | R_0603_1608Metric_Pad1,05x0,95mm_HandSolder | 5 | BLM18PG471
28 | L7 | L_CDRH4D28NP | 1 | 3,3uH
29 | L9,L8,L6 | R_1206_3216Metric_Pad1,42x1,75mm_HandSolder | 3 | BLM31PG601
30 | Q1 | SOT-23 | 1 | 2N7002
31 | Q2 | SOT-23 | 1 | IRLML5203
32 | R58,R53,R35,R32 | R_0603_1608Metric_Pad1,05x0,95mm_HandSolder | 4 | 0
33 | R16,R9,R46,R45,R44,R43 | R_0603_1608Metric_Pad1,05x0,95mm_HandSolder | 6 | 30
34 | R4,R3,R2,R1 | R_0603_1608Metric_Pad1,05x0,95mm_HandSolder | 4 | 50 | замена на 51
35 | R37,R41,R39,R8,R7 | R_0603_1608Metric_Pad1,05x0,95mm_HandSolder | 5 | 300
36 | R52 | R_0603_1608Metric_Pad1,05x0,95mm_HandSolder | 1 | 680
37 | R57,R49 | R_0603_1608Metric_Pad1,05x0,95mm_HandSolder | 2 | 820
38 | R6 | R_0603_1608Metric_Pad1,05x0,95mm_HandSolder | 1 | 1,5K
39 | R55,R54,R18,R14,R12,R19,R42 | R_0603_1608Metric_Pad1,05x0,95mm_HandSolder | 7 | 10K
40 | R5 | R_0603_1608Metric_Pad1,05x0,95mm_HandSolder | 1 | 12,1K 1%
41 | R27,R26,R25,R24,R23,R22,R21,R20,R10,R48 | R_0603_1608Metric_Pad1,05x0,95mm_HandSolder | 10 | 1K
42 | R36,R40,R38,R51,R50,R31,R30,R29,R28 | R_0603_1608Metric_Pad1,05x0,95mm_HandSolder | 9 | 3K
43 | R47 | R_0603_1608Metric_Pad1,05x0,95mm_HandSolder | 1 | 4,3K
44 | R56,R11 | R_0603_1608Metric_Pad1,05x0,95mm_HandSolder | 2 | 4,7K
45 | R34,R33,R17,R15,R13 | R_0603_1608Metric_Pad1,05x0,95mm_HandSolder | 5 | n,i,
46 | SW2,SW1 | SW_SPST_PTS645 | 2 | TACTM-64N-F
47 | U1 | QFN-24-1EP_4x4mm_P0,5mm_EP2,6x2,6mm | 1 | LAN8720A
48 | U10,U3 | SOT-23-5 | 2 | 74LVC1G04
49 | U11 | SOT-223-3_TabPin2 | 1 | MCP1826S33 | замена на LM2937-3.3
50 | U13,U12 | SOT-23-6 | 2 | 25AA02E48T
51 | U2 | Oscillator_SMD_SeikoEpson_SG8002CE-4Pin_3,2x2,5mm_HandSoldering | 1 | 50MHz OSC
52 | U4 | TSSOP-16_4,4x5mm_P0,65mm | 1 | ULN2003A
53 | U5 | TSSOP-16_4,4x5mm_P0,65mm | 1 | 74HC595
54 | U6 | LQFP-48_7x7mm_P0,5mm | 1 | STM32F072C8Tx
55 | U7 | SOT-23-6 | 1 | USBLC6-2SC6
56 | U8 | TSSOP-20_4,4x6,5mm_P0,65mm | 1 | 74HC245
57 | U9 | TI_SO-PowerPAD-8 | 1 | ST1S10PHR

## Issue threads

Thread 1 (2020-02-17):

[INFO] Are PCBs/kits available ?

amontefusco, 2020-02-17:
Hi,
nice project.

Are you going to publish PCB layouts or selling them?

UR3IQO, 2020-02-24:
Hi,
Currently I have no spare PCBs or kits. The spare boards I had earlier I gave to Pavel US4ICI. So, he has  several fully assembled and checked boards. He will probably sell some of them - please contact him for details.

It is still open question if AngeliaLite will become open hardware project. At this moment I have no such plans, but who knows...

amontefusco, 2020-02-25:
Ok, Thanks for the info.

Closed 2020-02-25.

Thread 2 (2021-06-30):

Документация

UN7RX, 2021-06-30:
Олег, добрый день.
Сорри за оффтоп, но я просто не мог не поблагодарить Вас за такую замечательную конструкцию абсолютно доступную для повторения, да еще и с рисунками ПП в pdf. Спасибо большое!

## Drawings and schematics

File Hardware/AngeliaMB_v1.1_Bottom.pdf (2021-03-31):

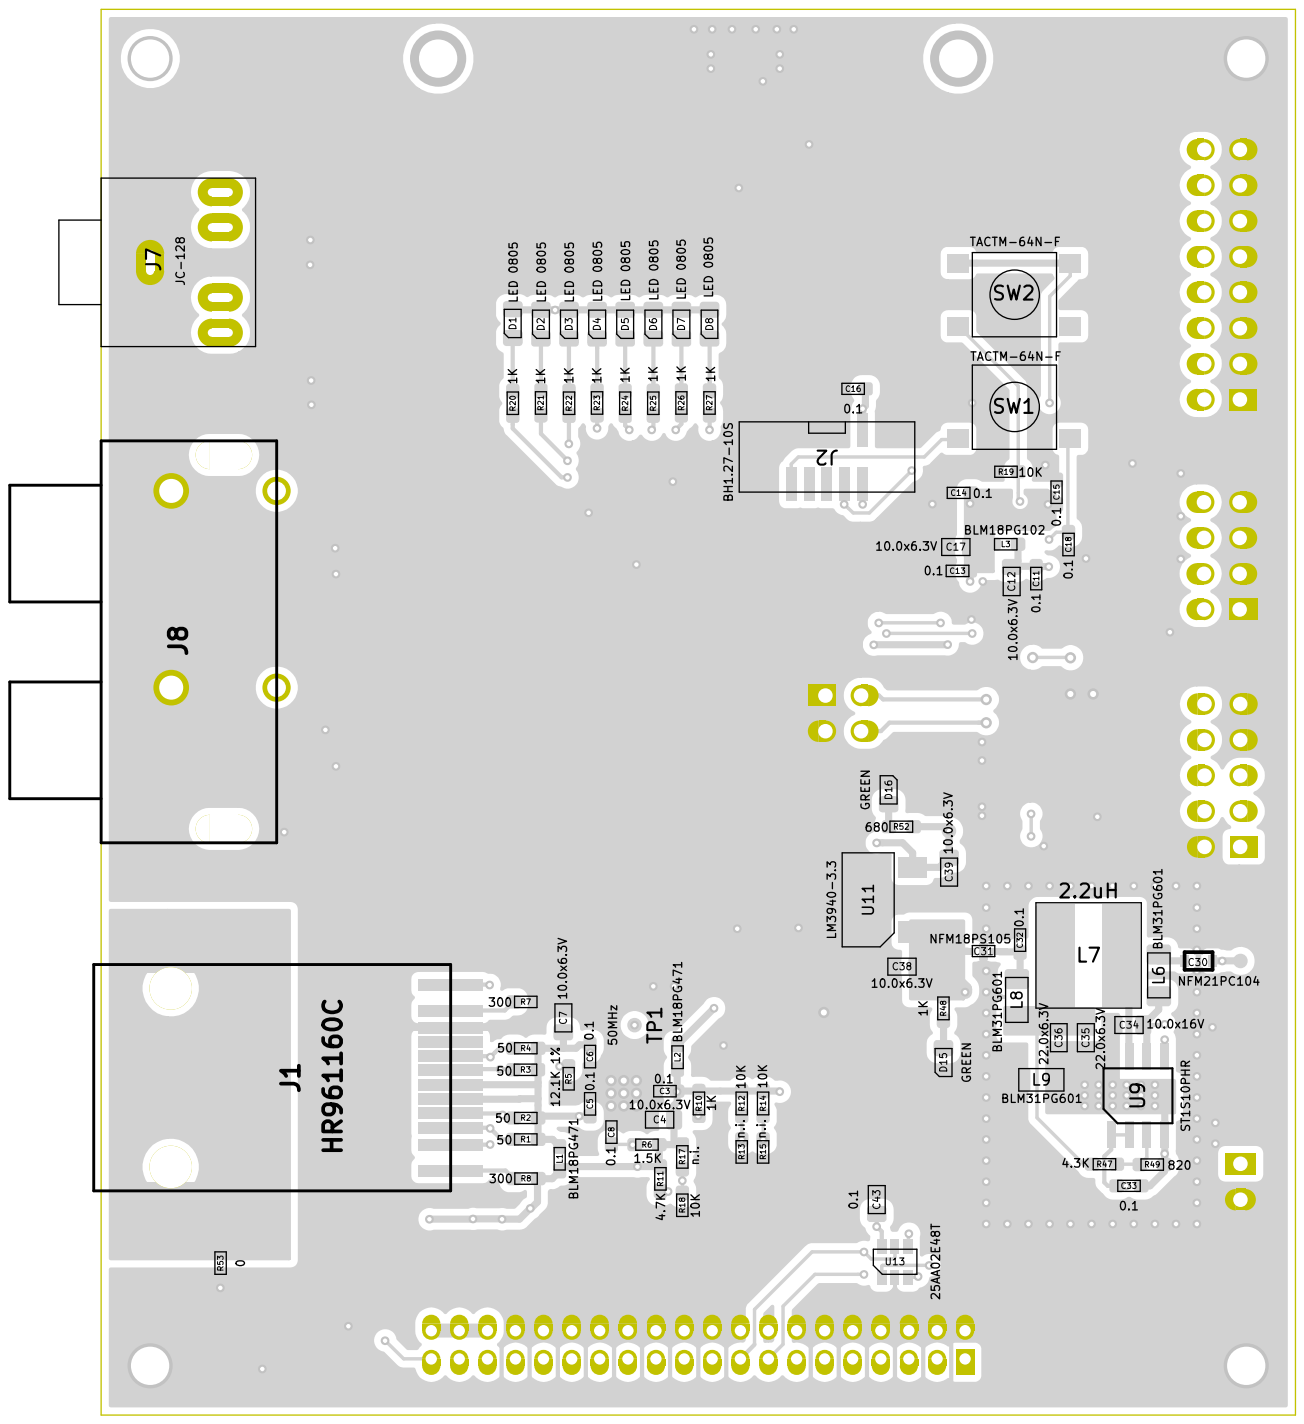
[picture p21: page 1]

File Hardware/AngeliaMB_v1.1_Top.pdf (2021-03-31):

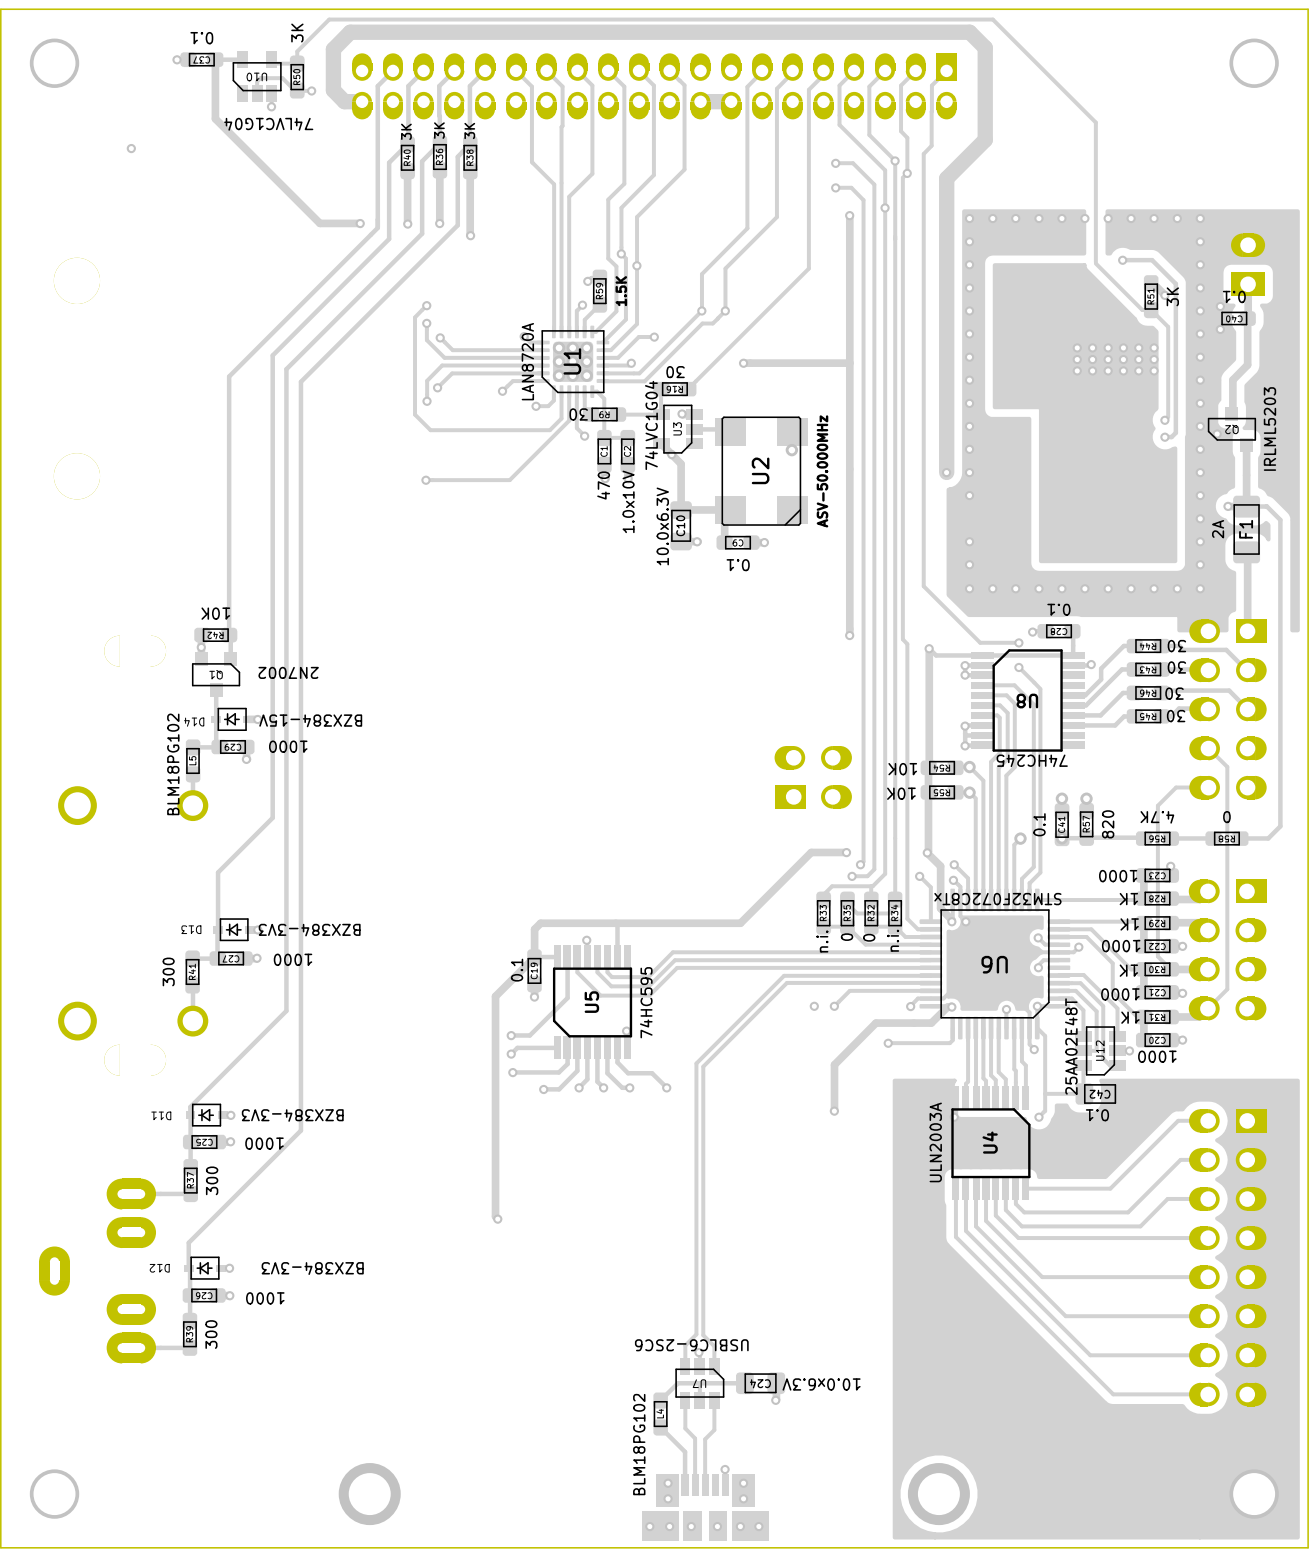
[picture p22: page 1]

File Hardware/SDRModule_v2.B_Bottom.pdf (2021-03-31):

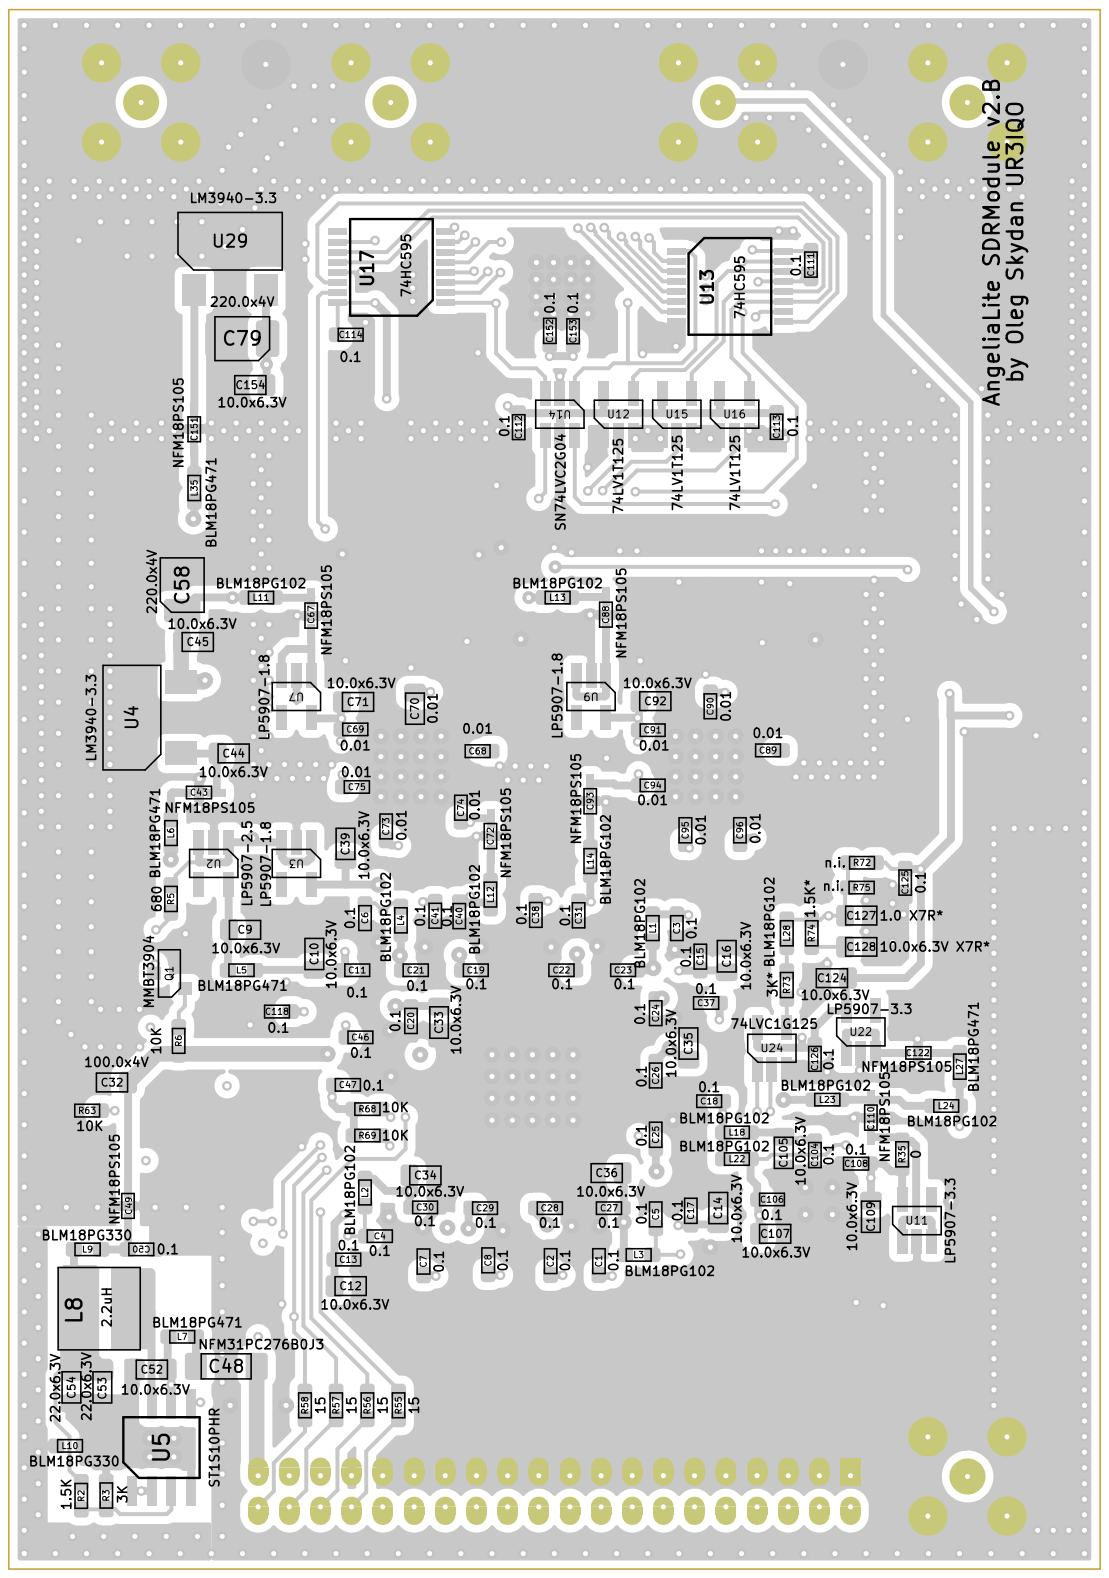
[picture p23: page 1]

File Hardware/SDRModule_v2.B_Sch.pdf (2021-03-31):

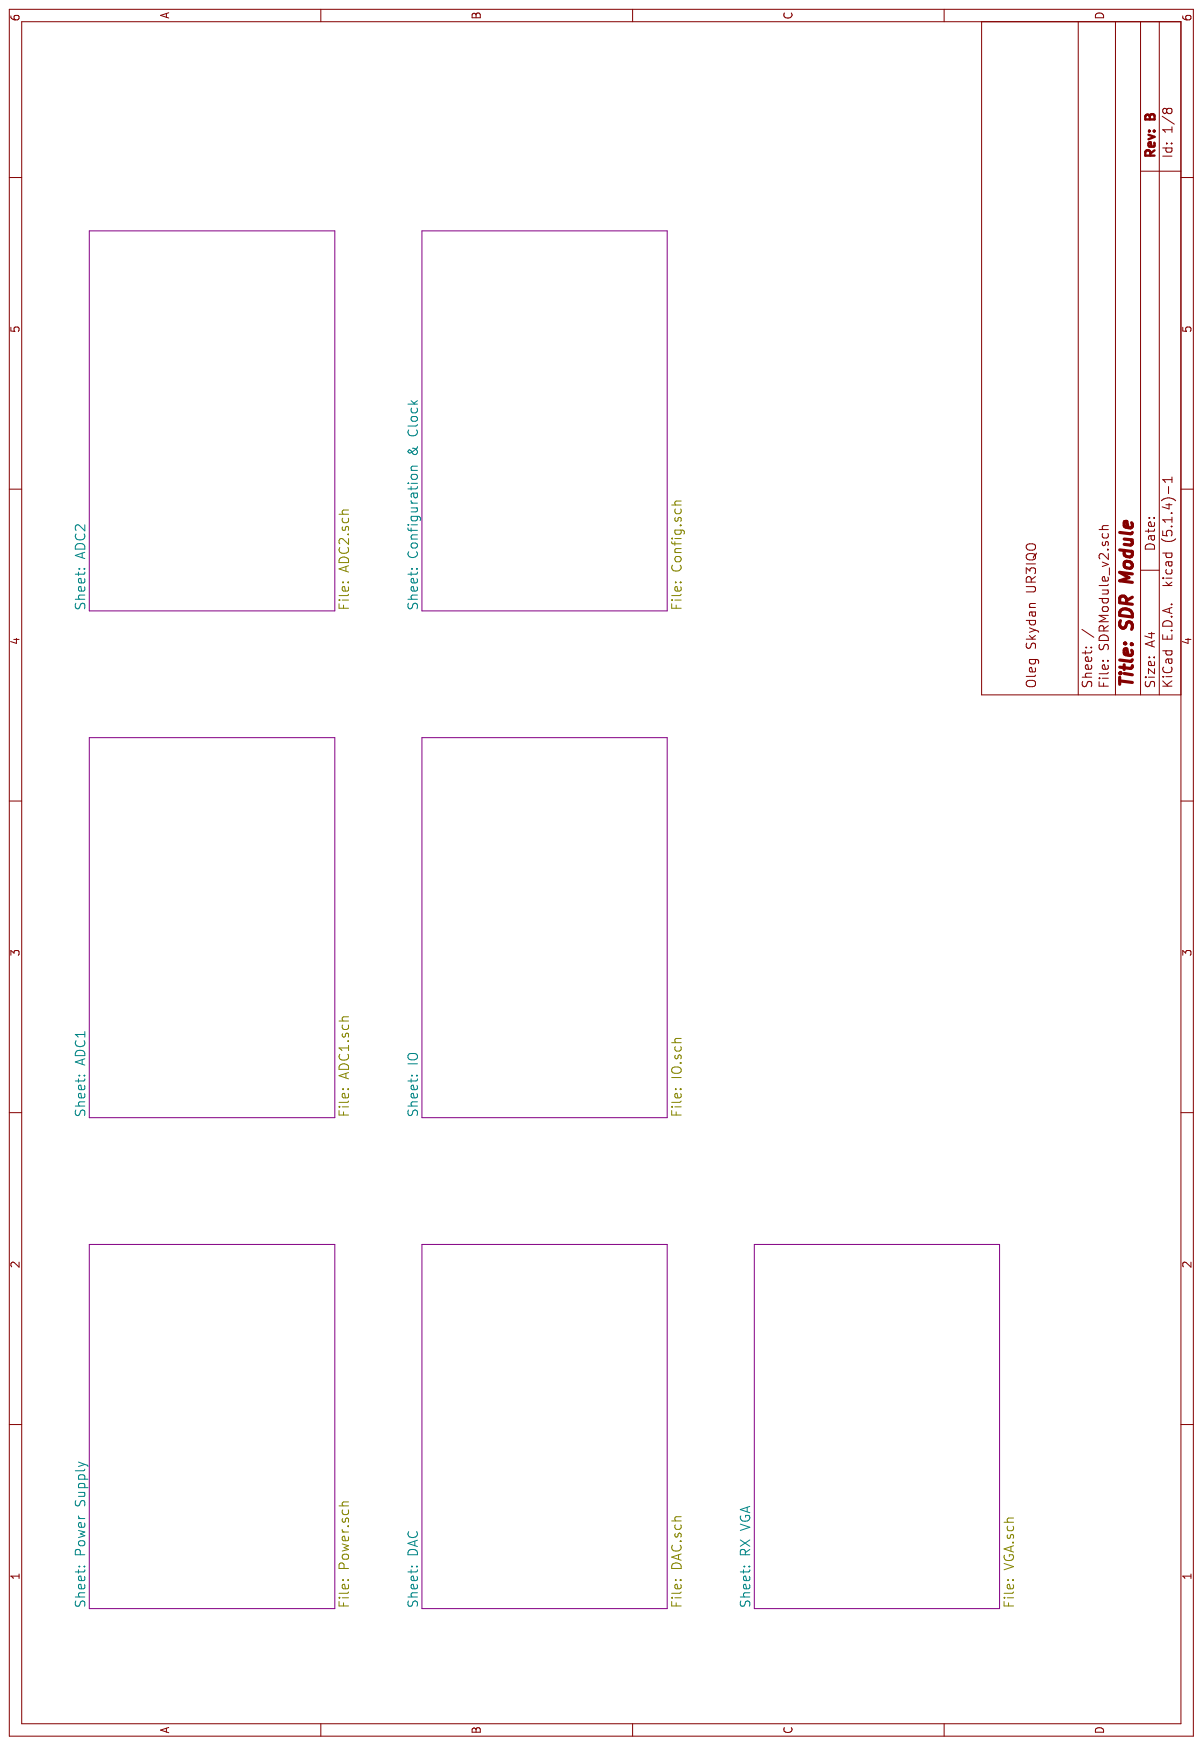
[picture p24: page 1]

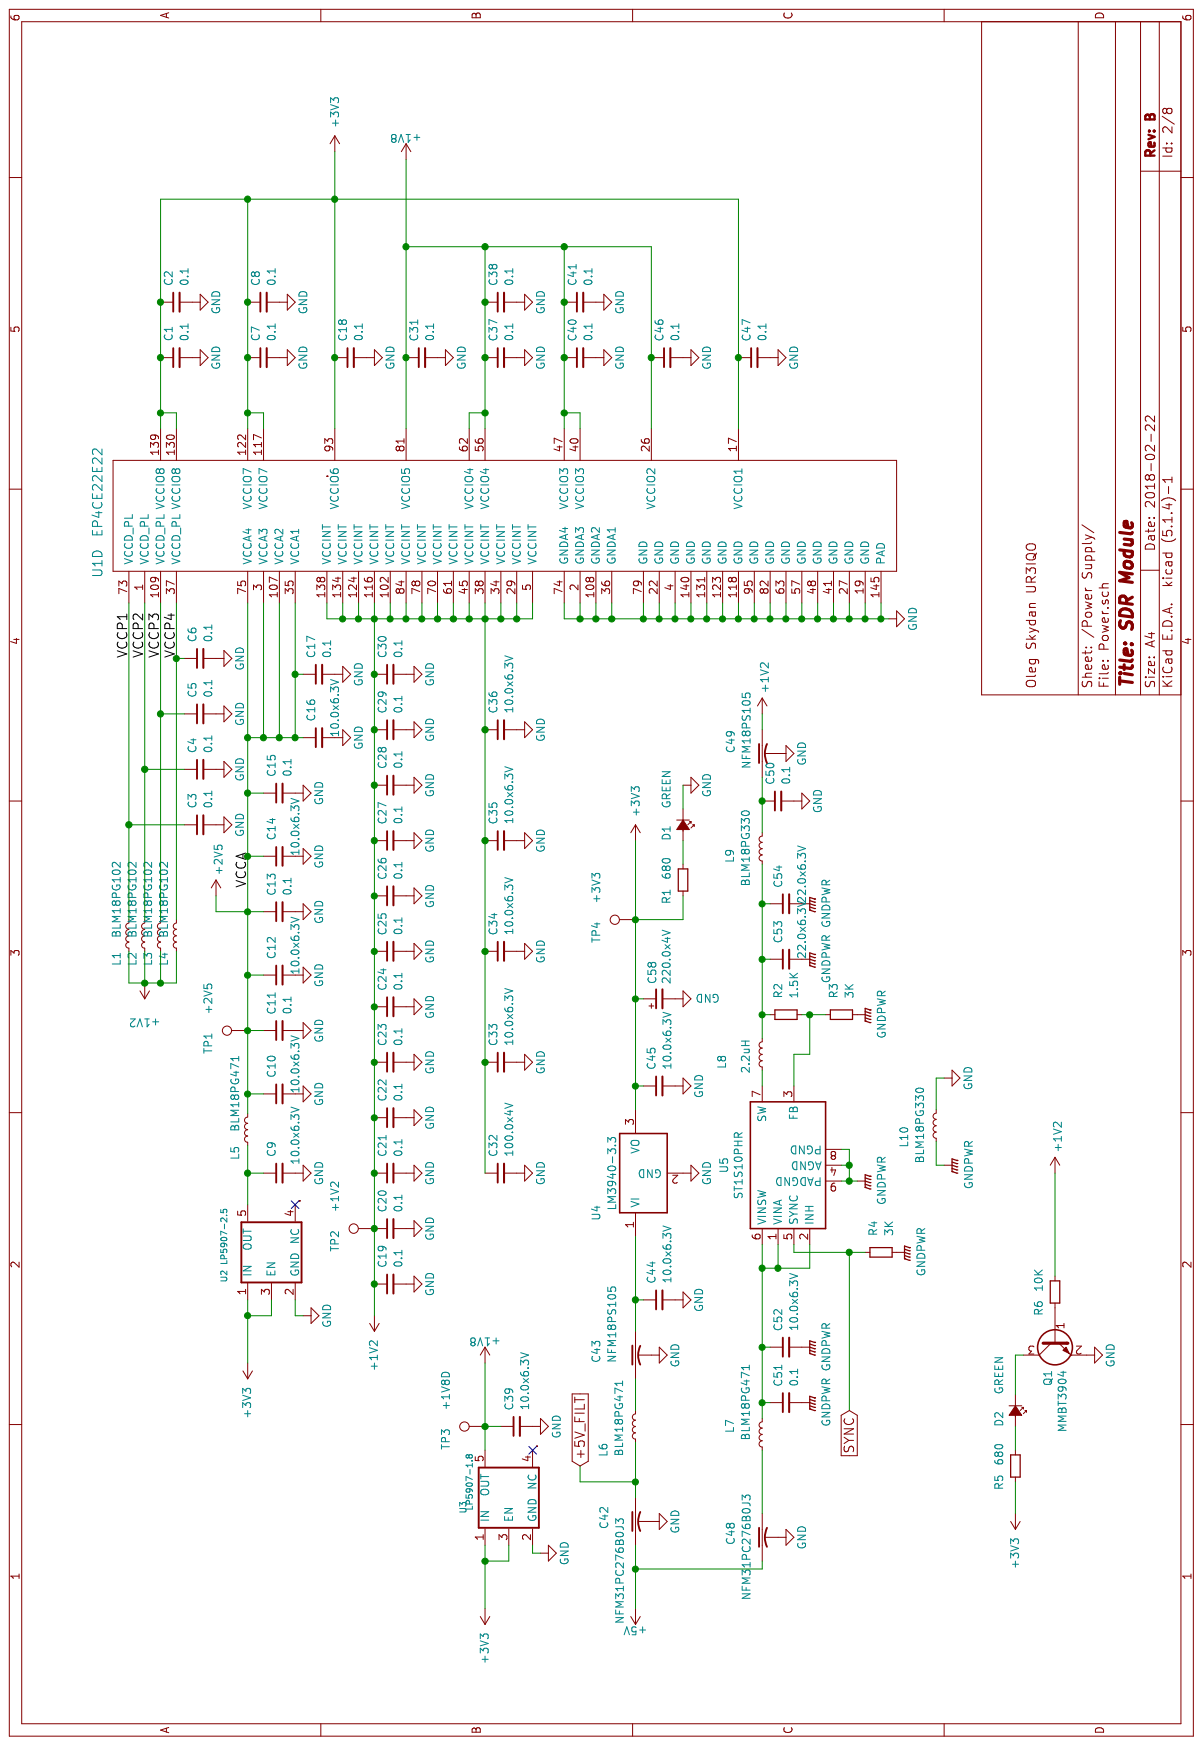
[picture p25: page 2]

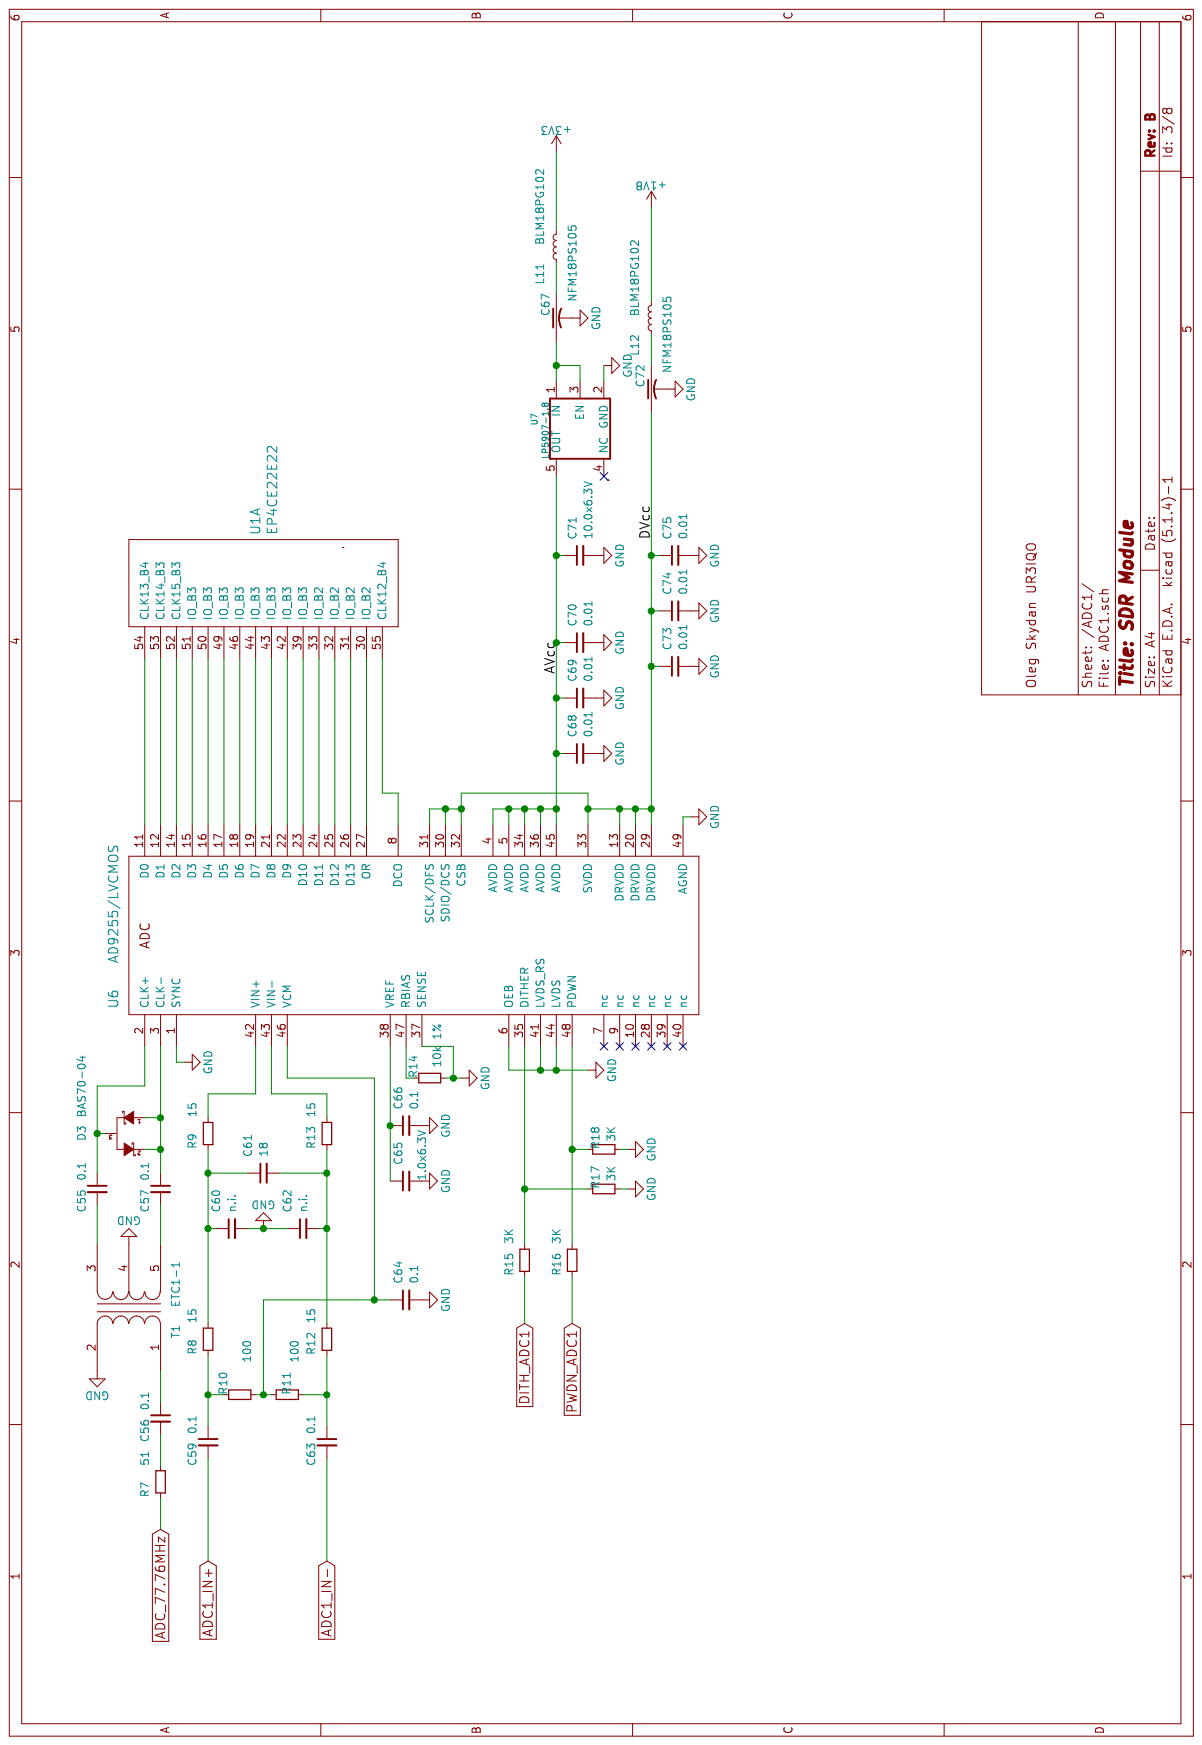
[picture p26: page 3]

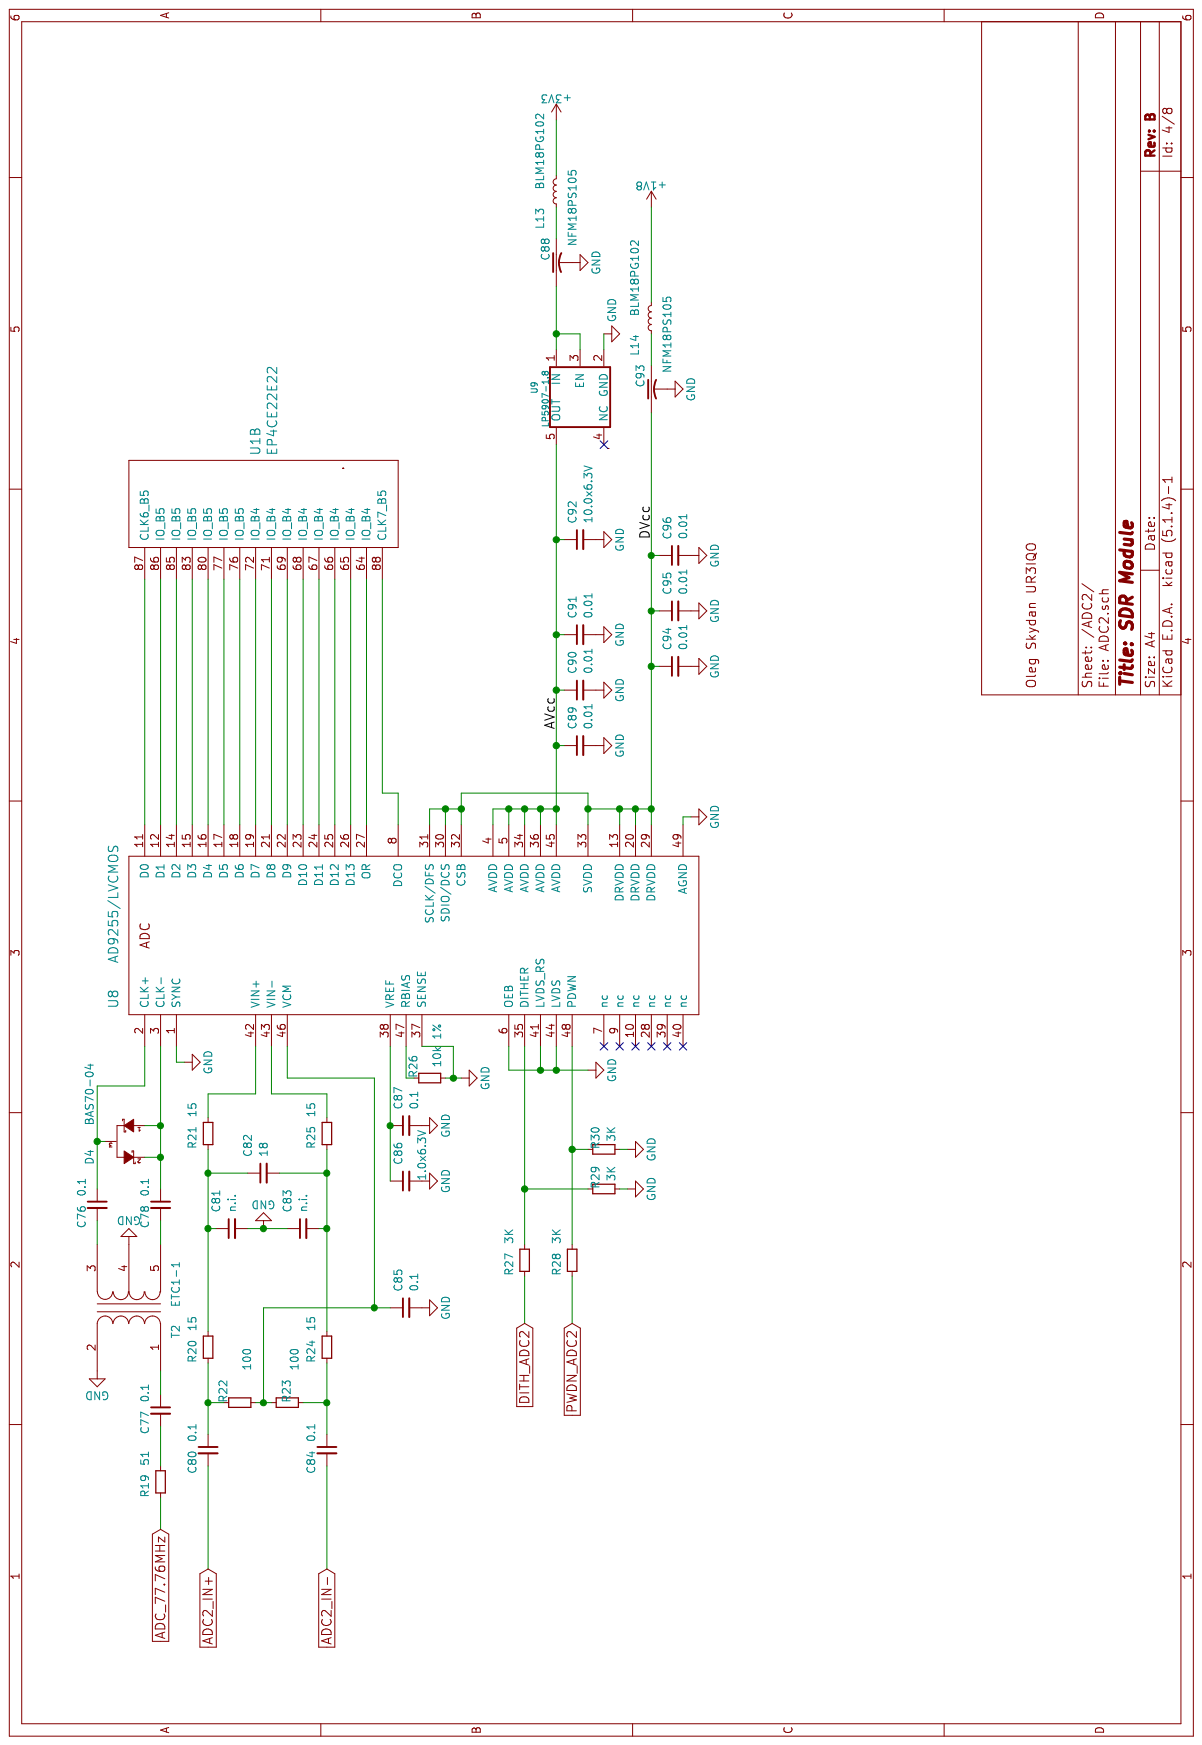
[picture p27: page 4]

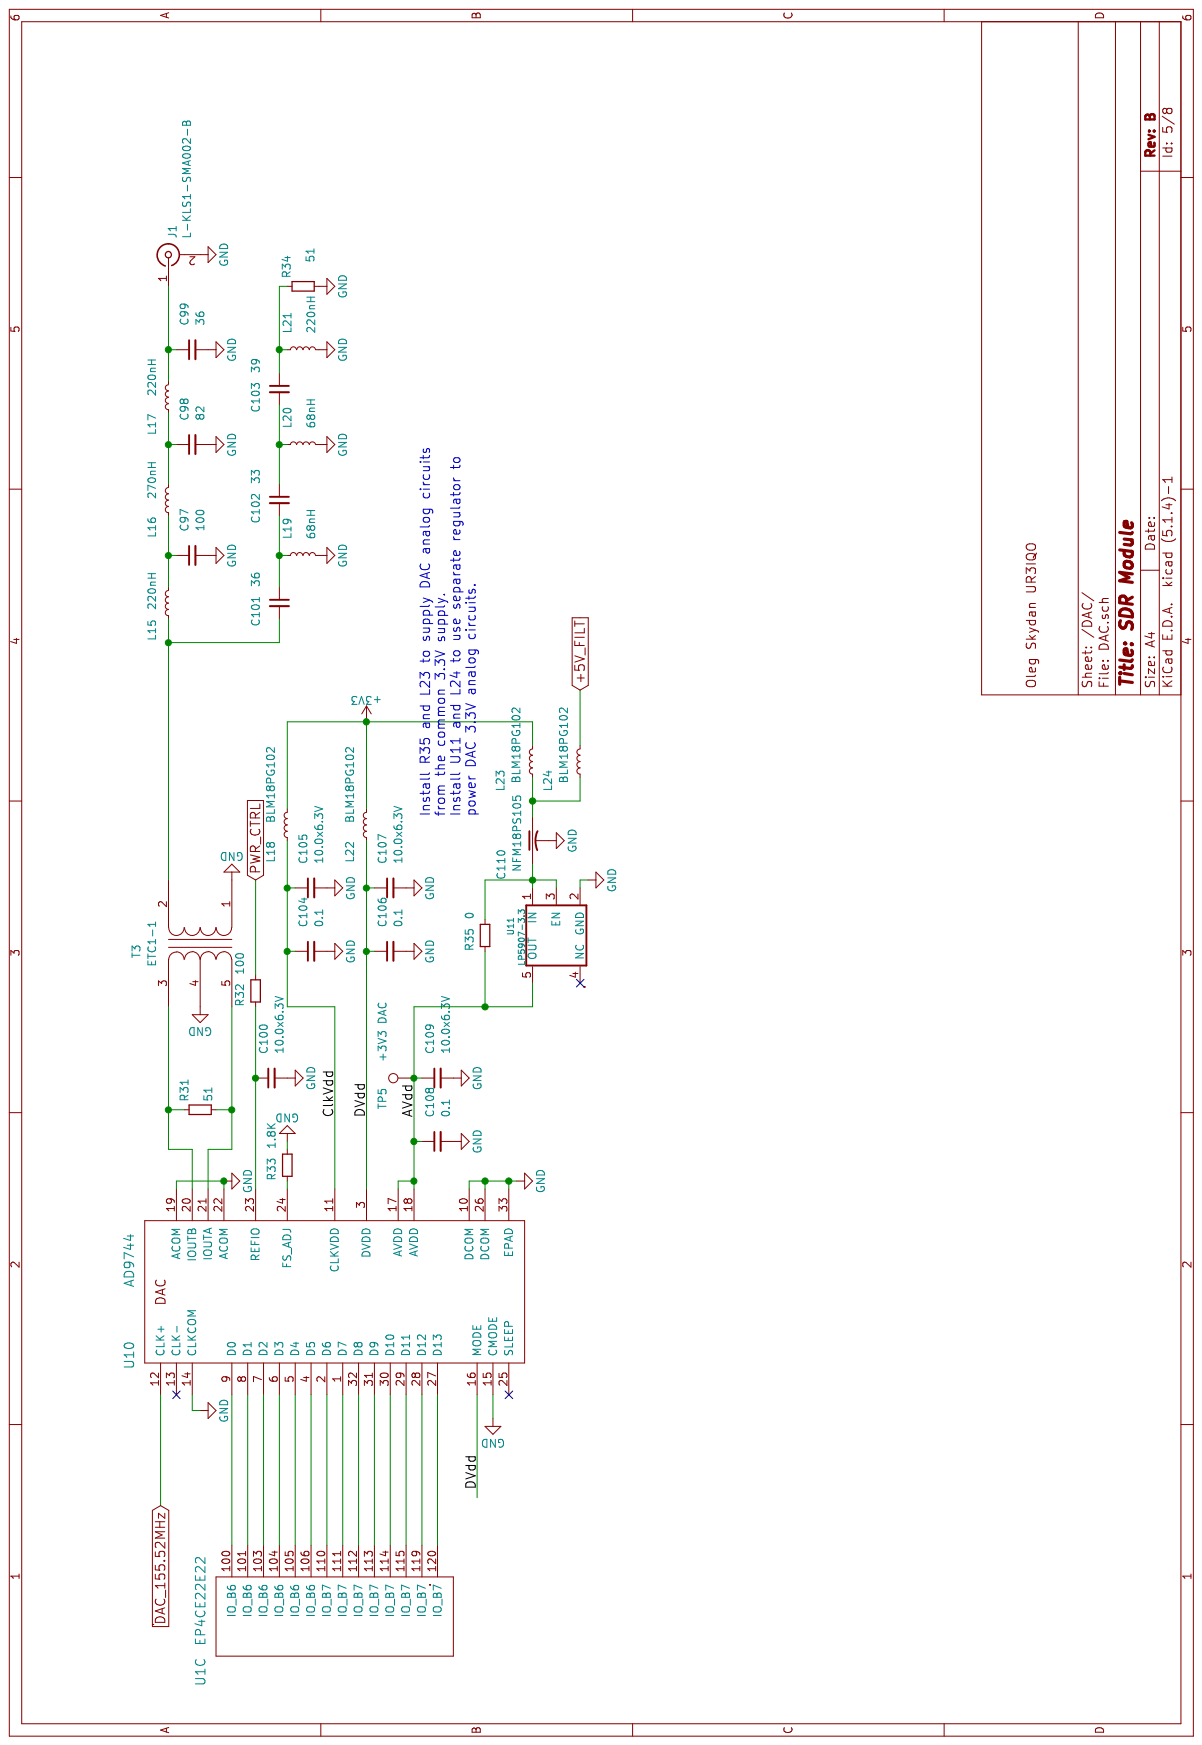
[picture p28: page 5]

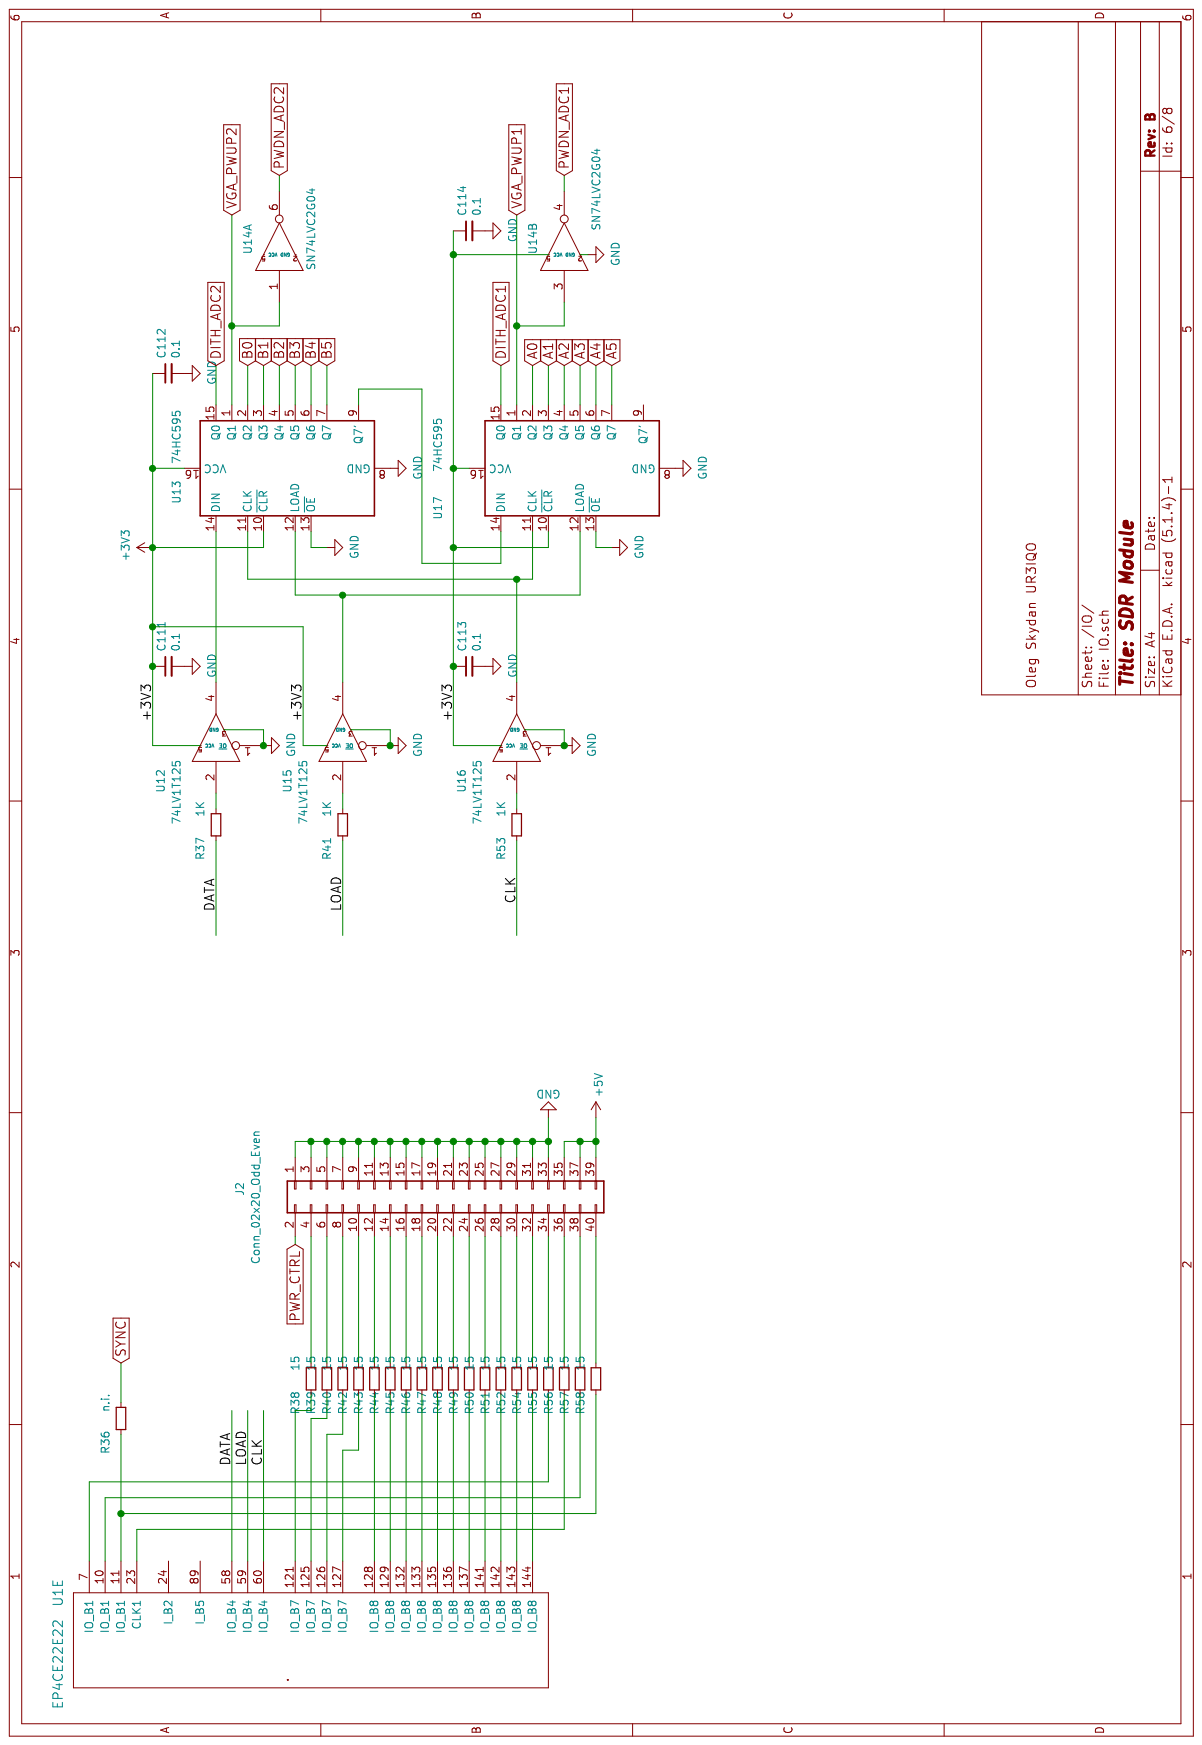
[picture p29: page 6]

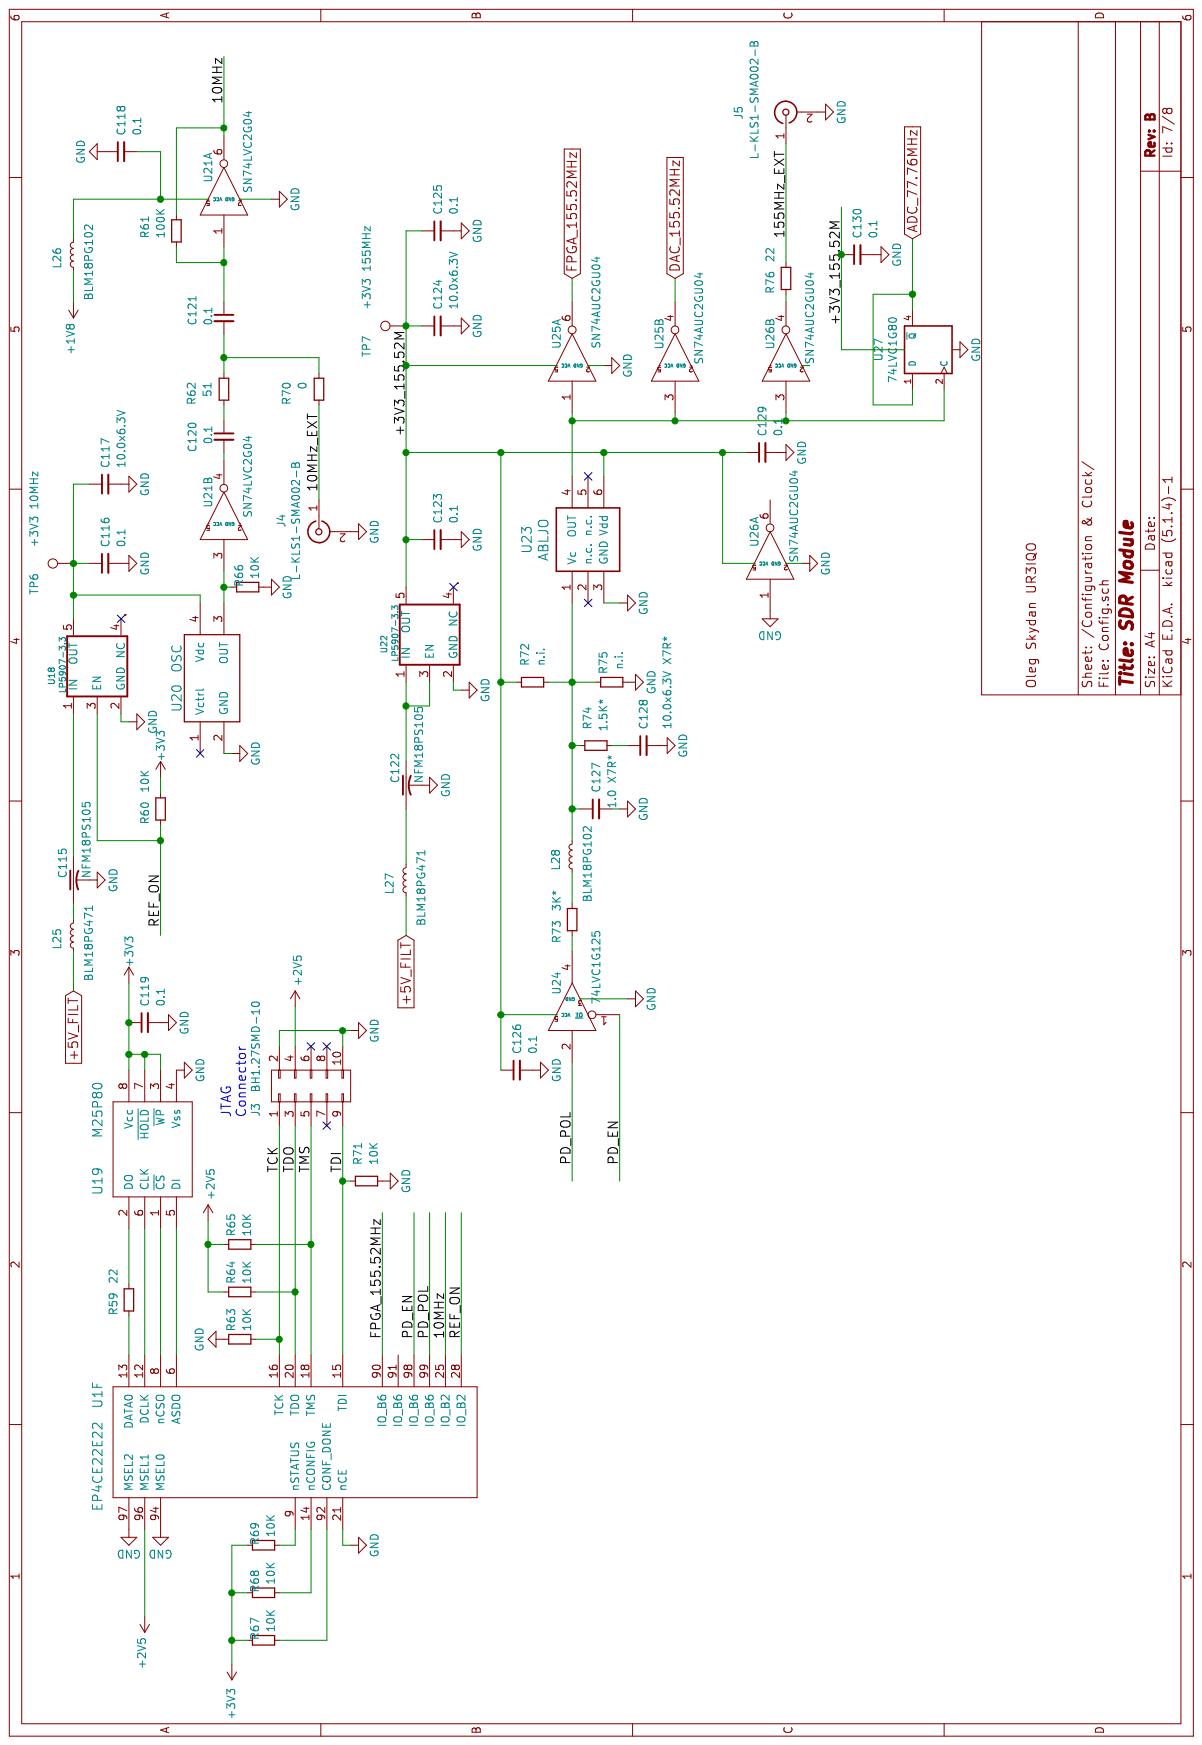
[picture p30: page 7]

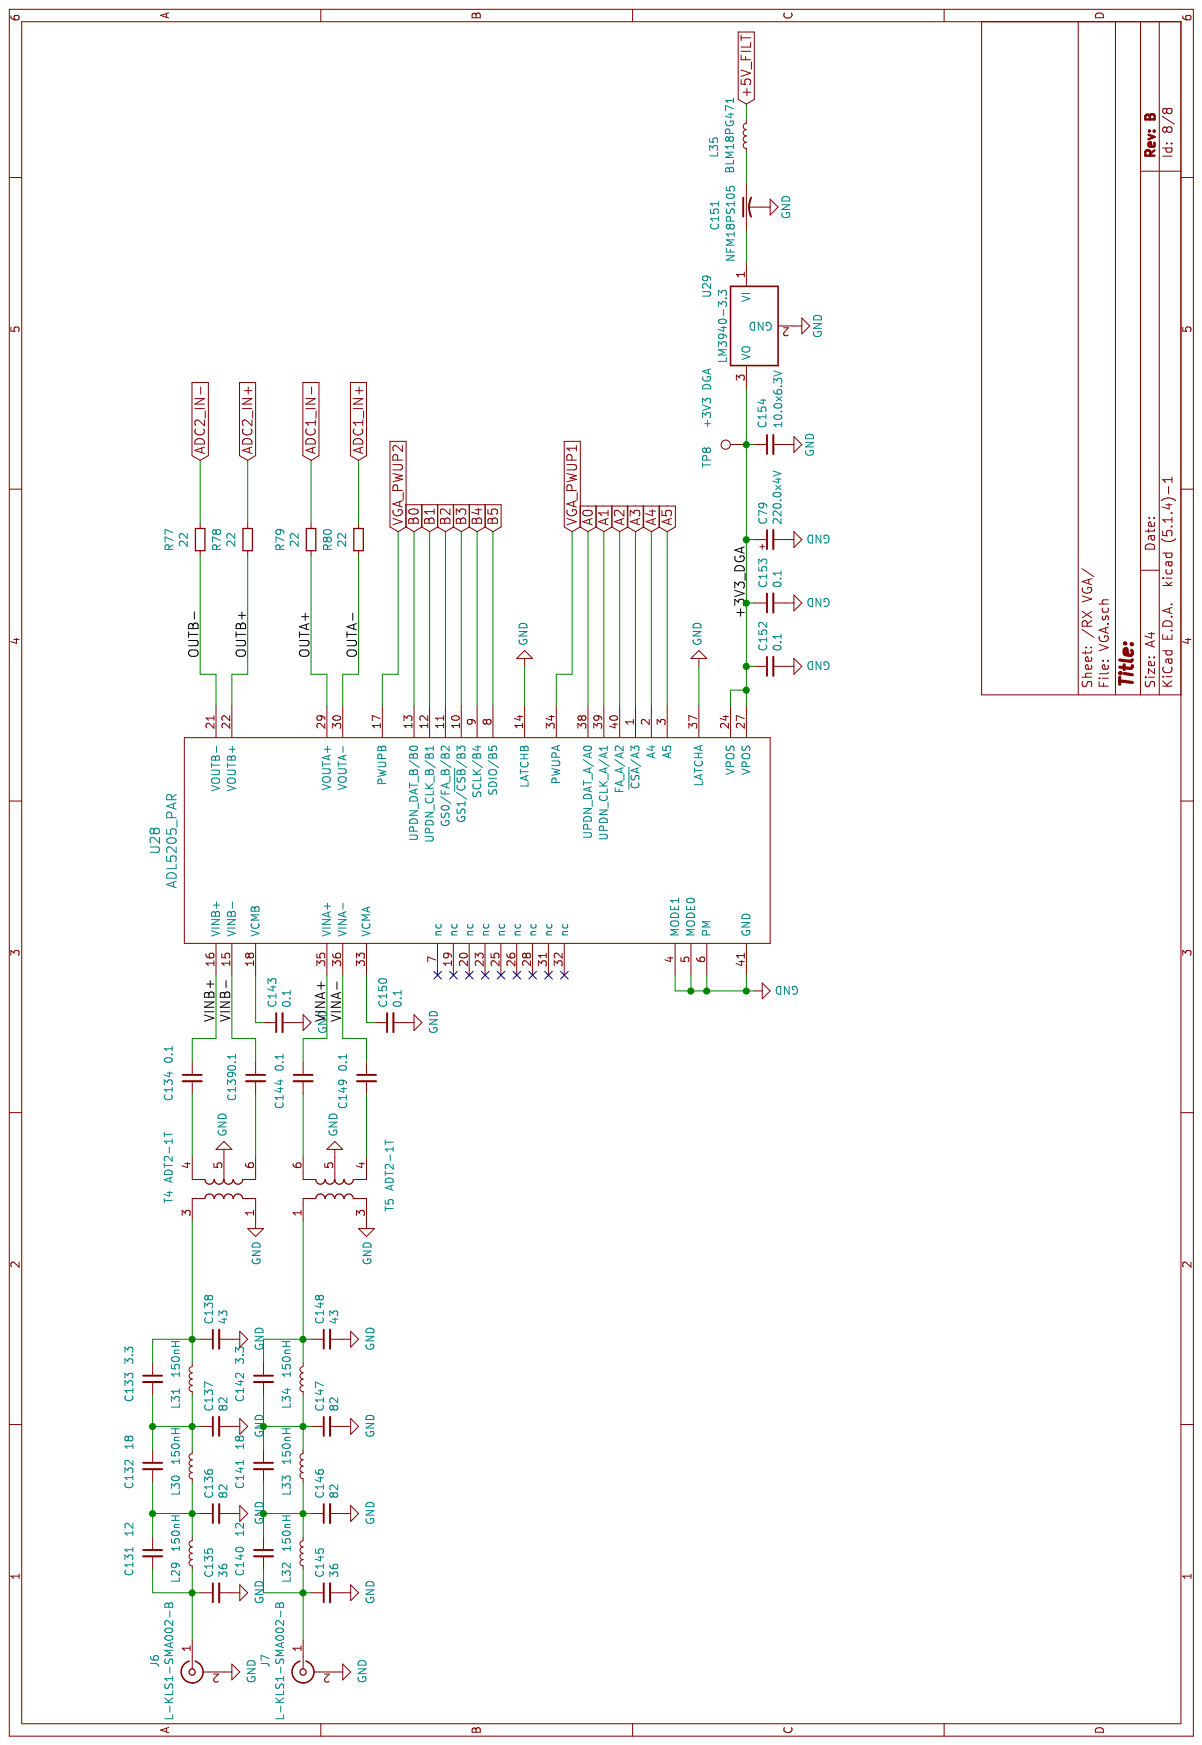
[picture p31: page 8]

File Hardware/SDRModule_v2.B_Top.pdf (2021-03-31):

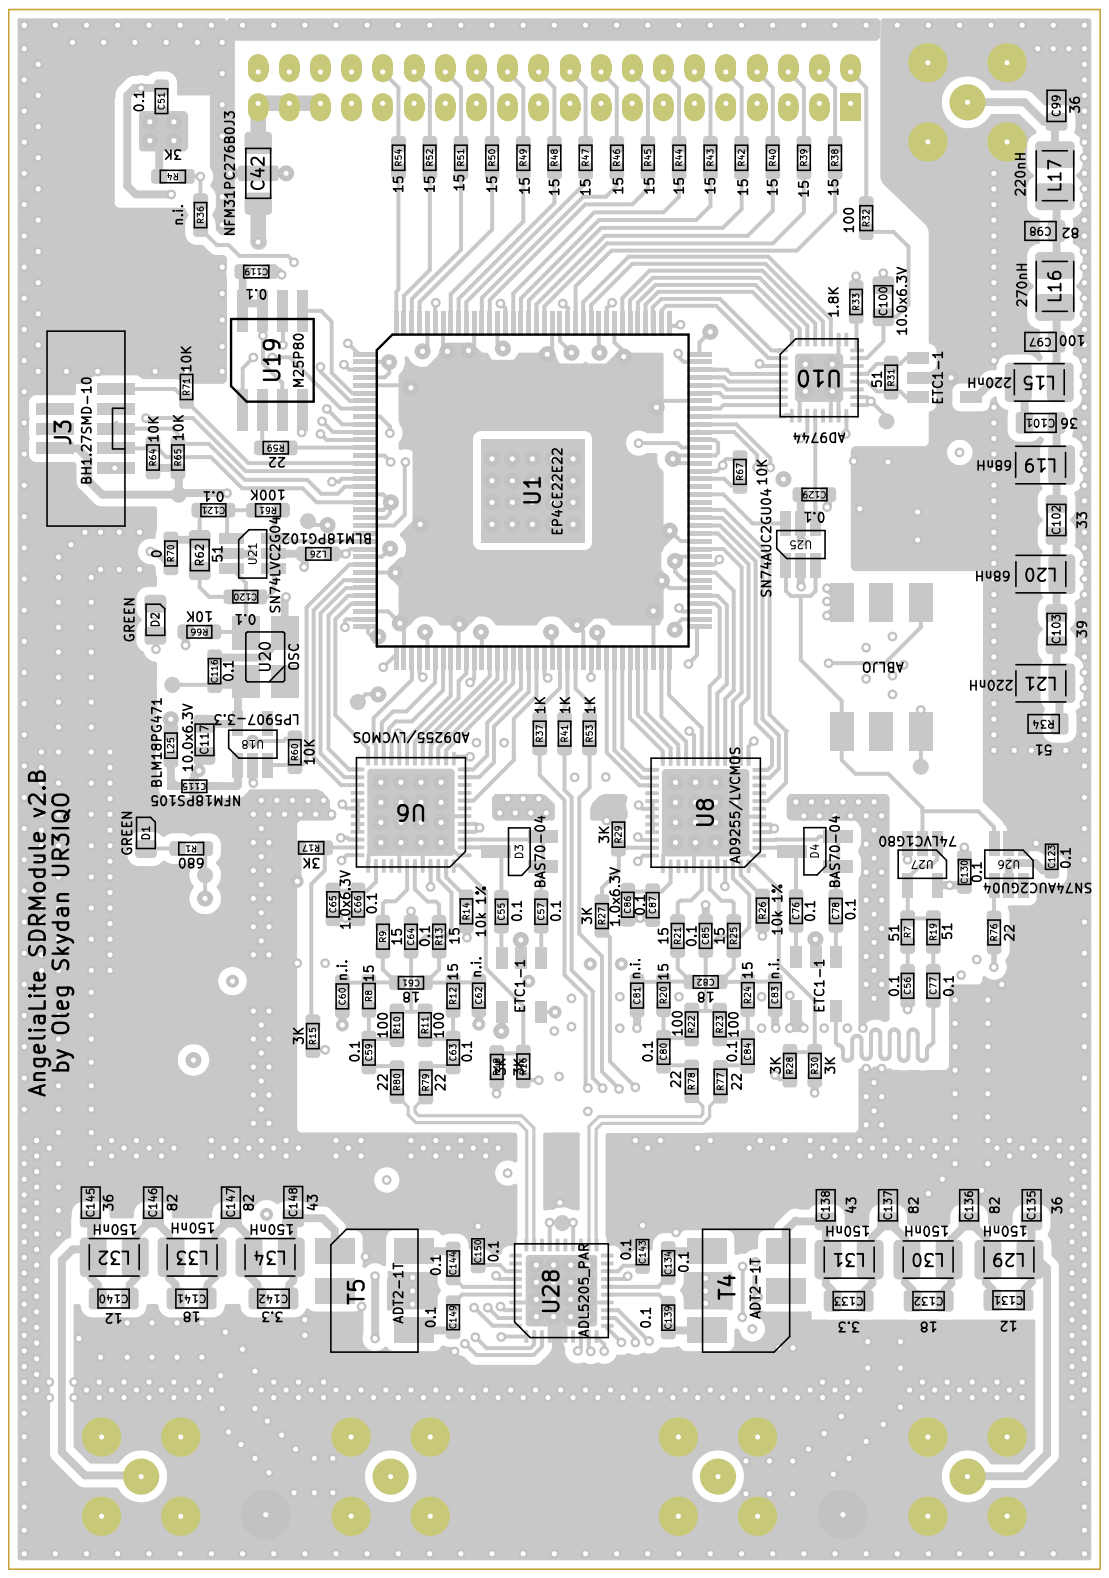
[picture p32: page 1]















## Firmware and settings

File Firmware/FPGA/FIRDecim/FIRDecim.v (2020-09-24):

//Decimation FIR filter. Optimized for resources (well, it can be more optimized, 
//but it fits in current FPGA, so no need to do it)  
//Copyright (C) by Oleg Skydan UR3IQO 2019


module FIRDecim (	
   input clock,
   input strobe_in,									// new sample is available
   input signed [IBITS-1:0] x_real,			// x is the sample input
   input signed [IBITS-1:0] x_imag,
   output reg strobe_out,							// new output is available
   output reg signed [OBITS-1:0] y_real,	// y is the filtered output
   output reg signed [OBITS-1:0] y_imag);
      
   parameter
      IBITS	 =  22,	  //input width	
      HBITS  =  18,   //taps width
      OBITS	 =  24,	  //output width
      RATIO  =  9,    //decimation ratio
      TAPS 	 =  774,  //taps number, must be even by RATIO and 2
      ABITS	 =  35,   //accumulator size fractional part
      GBITS  =  4;    //accumulator size integer part and sign bit

   localparam ADDRBITS  =  10,			//address bits for 18/54 X 1024 rom/ram blocks
              MBITS = IBITS + HBITS;   //multiple-add reslut size for h*(x[i]+x[N-i]) operation
                                       //We are adding two samples of IBITS width, the result is IBITS+1 width
                                       //After multiplication we have result of HBITS+IBITS+1 width with 
                                       //two sign bits. The most significant bit will be discarded.
                                       //So the result width is HBITS+IBITS
                                       //NOTE: MSB of the result should go to the GBITs part of the accumulator.


reg [ADDRBITS-1:0] addr_in = 0;
reg [ADDRBITS-1:0] x_addr_calc1 = 0;
reg [ADDRBITS-1:0] x_addr_calc2 = 0;
reg [ADDRBITS-2:0] h_addr_calc = 0;
reg signed [ABITS+GBITS-1:0] acc_r, acc_i;
reg [3:0] in_cnt = 0;

wire signed [IBITS-1:0] x1_r, x1_i, x2_r, x2_i;
wire signed [HBITS-1:0] h;

FIRDecimRAM X( .clock(clock), 
               
               .address_a(strobe_in ? addr_in : x_addr_calc1), 
               .wren_a(strobe_in), 
               .data_a({ x_real, x_imag }), 
               .q_a({x1_r, x1_i}),

               .address_b(x_addr_calc2),	
               .wren_b(1'b0),	
               .data_b(), 
               .q_b({x2_r, x2_i}) );   

FIRDecimROM H(.clock(clock), .address(h_addr_calc), .q(h));

reg strobe_in1;
reg strobe_in2;
reg strobe_in3;

reg [MBITS-1:0] mult_r, mult_i;

always @(posedge clock)
begin
   //Delay strobe_in pulse, it will be used to stop and synchronize 
   //different stages of pipline when the new sample is added to input delay line
   strobe_in1 <= strobe_in;
   strobe_in2 <= strobe_in1;
   strobe_in3 <= strobe_in2;

   if(strobe_in)
   begin
      //new input sample arrived
      //update delay line address for the next new sample
      addr_in <= addr_in - 1'b1;
      //count saved samples
      if(in_cnt == RATIO-1)in_cnt <= 0;
      else in_cnt <= in_cnt + 1'b1;
      //generate output strobe
      if(in_cnt == 0)strobe_out <= 1'b1;
      else strobe_out <= 1'b0;
   end
   else strobe_out <= 1'b0;

   if(h_addr_calc < TAPS/2 + 3 /*pipeline delay*/)
   begin
      if(!strobe_in)
      begin
         //increment addesses only if there is no new input sample
         //otherwise stall calc operation for one clock cycle until new sample
         //is written to the input delay line
         x_addr_calc1 <= x_addr_calc1 + 1'b1;
         x_addr_calc2 <= x_addr_calc2 - 1'b1;
         h_addr_calc <= h_addr_calc + 1'b1;
      end

      if(!strobe_in2)
      begin
         //propagate pipline stall 
         //multiply-add h[i]*(x[i]+x[N-i])
         mult_r <= h * (x1_r + x2_r);
         mult_i <= h * (x1_i + x2_i);
      end

      if(h_addr_calc == 2)
      begin
         //reset accumulators for the new FIR calculation cycle
         acc_r <= 0;
         acc_i <= 0;
      end
      else if(!strobe_in3)
      begin   
         //propagate pipline stall 
         //Round mult_r/mult_i down to ABITS width and fill GBITS with sign
         //The total accumulator size is GBITS + ABITS bits
         //GBITS are used to allow FIR gain > 1, so taps bits are used maximally effective 
         acc_r <= acc_r + { { (GBITS){ mult_r[ MBITS-1 ] }}, mult_r[ MBITS-2 : MBITS-ABITS-1 ] } + mult_r[MBITS-ABITS-2];
         acc_i <= acc_i + { { (GBITS){ mult_i[ MBITS-1 ] }}, mult_i[ MBITS-2 : MBITS-ABITS-1 ] } + mult_i[MBITS-ABITS-2];
      end   
   end
   else if(h_addr_calc == TAPS/2 + 3 /*pipeline delay*/)
   begin
      //round and register result
      y_real <= acc_r[ GBITS+ABITS-1 : GBITS+ABITS-OBITS ] + acc_r[ GBITS+ABITS-1-OBITS];
      y_imag <= acc_i[ GBITS+ABITS-1 : GBITS+ABITS-OBITS ] + acc_i[ GBITS+ABITS-1-OBITS];
      h_addr_calc <= h_addr_calc + 1'b1;
   end
   else
   begin
      if(in_cnt == 0)
      begin
         //run new FIR caclulation cycle
         x_addr_calc1 <= addr_in;
         x_addr_calc2 <= addr_in + (TAPS[ADDRBITS-1:0] - 1'b1);
         h_addr_calc <= 0;
      end
   end
end


endmodule

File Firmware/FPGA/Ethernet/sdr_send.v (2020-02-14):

//-----------------------------------------------------------------------------
//                          sdr send
//-----------------------------------------------------------------------------

//
//  HPSDR - High Performance Software Defined Radio
//
//  Metis code. 
//
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

//  Metis code copyright 2010, 2011, 2012, 2013, 2014, 2015 Phil Harman VK6(A)PH
//  April 2019, UR3IQO Changed to work in AngeliaLite  (LAN8720A PHY, 100Mbit/s speed)


module sdr_send(
	input tx_clock,
	input udp_tx_active,
	input run,
	input wideband,
	input [47:0]local_mac,
	input [7:0] code_version,
	input discovery, 
	input [7:0]Rx_data[0:NR-1] /* ramstyle = "logic" */,			// Rx data to send to PHY
	input sp_data_ready,
   input [7:0] sp_fifo_rddata,
	input udp_tx_enable,
	input erase_done,						// set to send EPCS16 erased to PC
	input send_more,						// set to request more EPCS16 data
	input [7:0]Mic_data,
	input fifo_ready[0:NR-1],
	input mic_fifo_ready,
	input CC_data_ready,
	input [7:0]CC_data[0:55], 			//[7:0]CC_data[0:56],
	input [31:0] sequence_number,		// sequence number to send when programming and requesting more data.	
   input [15:0]samples_per_frame[0:NR-1],	
	input [15:0]tx_length[0:NR-1],		// length of the UDP packet, varies with number of sync or mux receivers.
	input [7:0] Wideband_packets_per_frame,  // 
	output reg udp_tx_request,
	output [7:0] udp_tx_data,
	output reg [15:0] udp_tx_length,
	output reg fifo_rdreq[0:NR-1],	// high to indicate read from Rx fifo required
	output reg sp_fifo_rdreq,	   	// high to indicate read from wideband spectrum fifo required
	output reg mic_fifo_rdreq,			// high to indicate read from mic fifo required
	output reg send_more_ACK,
	output reg erase_done_ACK,
	output reg [7:0] port_ID,
	output reg CC_ack,
	output reg WB_ack,
	output reg phy_ready,				// this set when no DDC data is being sent. Used when changing modes for PureSignal
	output reg discovery_ACK			// set to indictate that a discovery reply has been received. 
);

parameter board_type,
			 NR,
			 master_clock,
			 protocol_version;

localparam
    IDLE        = 10'd0,
    RX_SEND     = 10'd1,
    RX_SEND_2   = 10'd2,
    WIDEBAND    = 10'd4,
    WIDEBAND_2  = 10'd8,
    response    = 10'd16,
    SEND        = 10'd32,
    MIC_SEND    = 10'd64,
    MIC_SEND_2  = 10'd128,
    CC_SEND     = 10'd256,
    CC_SEND_2   = 10'd512;
	
	
	
	
	
localparam 
	HEADER_LENGTH  = 16'd22,					// number of bytes in response  udp header
	PC_LENGTH		= 16'd4,						// number of bytes in sequence number
	RES_H_BIT    	= HEADER_LENGTH*8 -1,  	// response header bits
	PC_H_BIT       = PC_LENGTH*8 -1,
	FRAME				= 8'h01; 					// HPSDR Frame type

	
//(* ramstyle = "logic" *) reg [31:0] Rx_sequence_number[0:7];	// use registers for speed.
reg [31:0] Rx_sequence_number[0:NR-1];	
reg [31:0] spec_seq_number = 0;
reg [31:0] mic_seq_number = 0;
reg [31:0] CC_seq_number = 0;
reg [7:0]  status;
reg [7:0]  wideband_count = 0;  // max of 255 blocks = 255 * 512 = 130,560 samples 
reg send_wb_block;
reg [7:0]  select;					// used to select data on mux and demux. *** increase when more Rx added *****
reg [7:0] tx_data;
reg [63:0] time_stamp = 0;
reg [15:0] bits_per_sample = 16'd24;
reg [15:0] samples_frame;
wire [15:0] UDP_lenght[0:NR-1];

// response payload followed by 50 x 0x01
reg [RES_H_BIT:0] response_tx_bits; // new protocol

//shift register
reg [RES_H_BIT:0] response_shift_reg;
reg [PC_H_BIT:0] PC_shift_reg;

reg [15:0] byte_no = 16'd0;
reg [9:0] state = 0;
reg [7:0] port_index = 8'd0;
reg send_response = 0;
//reg [$clog2(NR):0]i,j,k;
integer i,j;

reg [28:0] stuck_cnt = 29'd0;
wire [7:0] number_Rx = NR;
//wire [31:0] clock_frequency = master_clock;


always @(posedge tx_clock) 
  begin
  if ((state > IDLE) && !run) begin				// prevents code getting stuck when run not active
      if (stuck_cnt < 29'd250000000)
          stuck_cnt <= stuck_cnt + 29'b1;
      else begin
          state <= IDLE;
          stuck_cnt <= 29'd0;
      end
  end

  case (state)
		IDLE: 
			begin
				udp_tx_request <= 1'b0;
				send_response <= 1'b0;
				byte_no <= 16'd0; 
				port_ID <= 8'd0;										// set base to 1024
				if (!send_more)  send_more_ACK  <= 1'b0;		// clear ACK when sdr_receiver has seen our ACK
				if (!erase_done) erase_done_ACK <= 1'b0;		// clear ACK when ASMI_interface has seen our ACK
				if (!discovery)  discovery_ACK  <= 1'b0;		// clear ACK when sdr_receiver has seen our ACK
				if (!wideband) spec_seq_number <= 32'd0;
				
				// *** NOTE: can reply to Discovery if already running *****	
				if (discovery) begin
					response_tx_bits <= {32'd0, (8'd02 + {7'b0,run}), local_mac, board_type, protocol_version, code_version,  48'd0, number_Rx, 8'd1}; 	// sequence number set to zero for future use
					state <= response;			// **** change HEADER_LENGTH when making changes here ****
				end 
				
				else if (erase_done) begin
					response_tx_bits <= {32'd0, 8'd03, local_mac, code_version, board_type, 72'd0}; 	// sequence number set to zero for future use
					state <= response;
				end 
				
				else if (send_more) begin
					response_tx_bits <= {sequence_number, 8'd04, local_mac, code_version, board_type, 72'd0}; 
					state <= response;
				end 
						
				else if (run && CC_data_ready) state <= CC_SEND;    // highest priority data 
				
				else if (run && mic_fifo_ready) state <= MIC_SEND;
				
				else if (run && wideband && sp_data_ready) state <= WIDEBAND;  // do for first WB packet
				
				else if (run)				
				begin
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

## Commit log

2020-02-24 Timings, static IP, ADC powerdown, code cleanup - Updated SDC rules and sources, so timing requirements are met now - Data widths were optimized - resulting in less articacts and better filtering, 48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
2020-09-17 Updates boards pictures
2021-03-01 Added FPGA JTAG Adapter schematics and gerbers
    [FPGA_Prog_Adapter-B_Cu.gbr, FPGA_Prog_Adapter-B_Mask.gbr, FPGA_Prog_Adapter-B_SilkS.gbr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]
2021-03-31 ADD: Added schematics and boards assembly files
    [AngeliaMB_v1.1_BOM.xls]
2023-10-04 Fixed incorrect USB device name
2024-04-28 Added important assembly instructions to README.md

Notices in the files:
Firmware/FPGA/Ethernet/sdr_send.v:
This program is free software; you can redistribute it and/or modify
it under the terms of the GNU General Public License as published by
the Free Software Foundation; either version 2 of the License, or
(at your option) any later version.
